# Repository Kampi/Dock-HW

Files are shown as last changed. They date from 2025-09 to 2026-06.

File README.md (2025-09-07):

# ZSWatch-Dock



## 📑 Table of Contents

- [ZSWatch-Dock](#zswatch-dock)
  - [📑 Table of Contents](#-table-of-contents)
  - [📖 About](#-about)
  - [📂 Directory Breakdown](#-directory-breakdown)
  - [Purchasing](#purchasing)
  - [Ressources](#ressources)
  - [👨‍💻 Maintainer](#-maintainer)

## 📖 About

The **ZSWatch-Dock** project provides the hardware design and production files for a docking station tailored to the ZSWatch ecosystem.  
It is built with **KiCad** and integrates a full **CI/CD pipeline** using **KiBot**, ensuring reproducible outputs for documentation, manufacturing, and releases.

Key features:

- 🛠️ Open-source hardware design
- 📦 Automated generation of Gerber, BoM, and documentation via KiBot
- 🔄 Workflow stages (DRAFT → PRELIMINARY → CHECKED → RELEASED) for structured releases
- 📝 Clear documentation and changelog to track progress
- 🌍 Designed with collaboration and transparency in mind

Please check the [wiki](https://github.com/ZSWatch/ZSWatch/wiki) for more information about the project.

## 📂 Directory Breakdown

- **`.github`**: GitHub related files
- **`.gitignore`**: Ignored files list
- **`dock`**: KiCad project for the dock
- **`production`**: Manufacturing outputs (Gerbers, documentation, etc.)
- **`CHANGELOG.md`**: Version history
- **`LICENSE`**: Project license (GPL-3.0)
- **`README.md`**: Project overview

## Purchasing

TBD

## Ressources

- [KiBot Template](https://github.com/nguyen-v/KDT_Hierarchical_KiBot)

## 👨‍💻 Maintainer

- [Daniel Kampert](mailto:danielkameprt@kampis-elektroecke.de)
- [Jakob Krantz](mailto:mail@jakobkrantz.se)

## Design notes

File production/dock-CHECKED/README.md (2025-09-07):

<p align="center" width="100%">
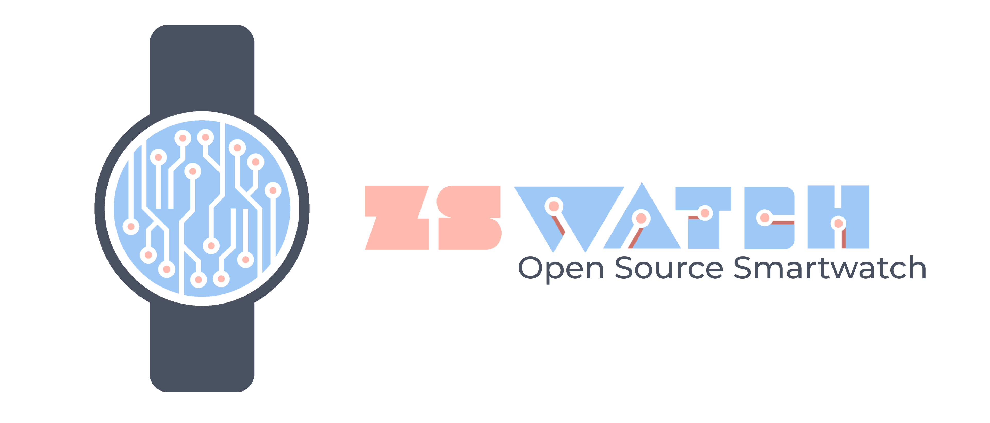
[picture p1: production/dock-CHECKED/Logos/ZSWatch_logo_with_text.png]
  
</p>

<h1 align="center">Dock-HW</h1>

<p align="center" width="100%">
  <a href="https://github.com/ZSWatch/Dock-HW/actions/workflows/dock.yaml">
    
  </a>
</p>

***

<p align="center">
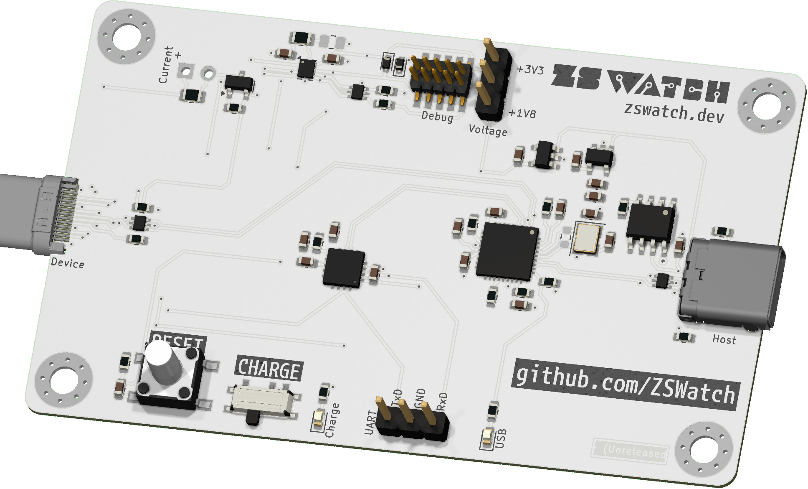
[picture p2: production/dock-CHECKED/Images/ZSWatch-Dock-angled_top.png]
3D Top Angled
  
&nbsp; &nbsp; &nbsp; &nbsp;
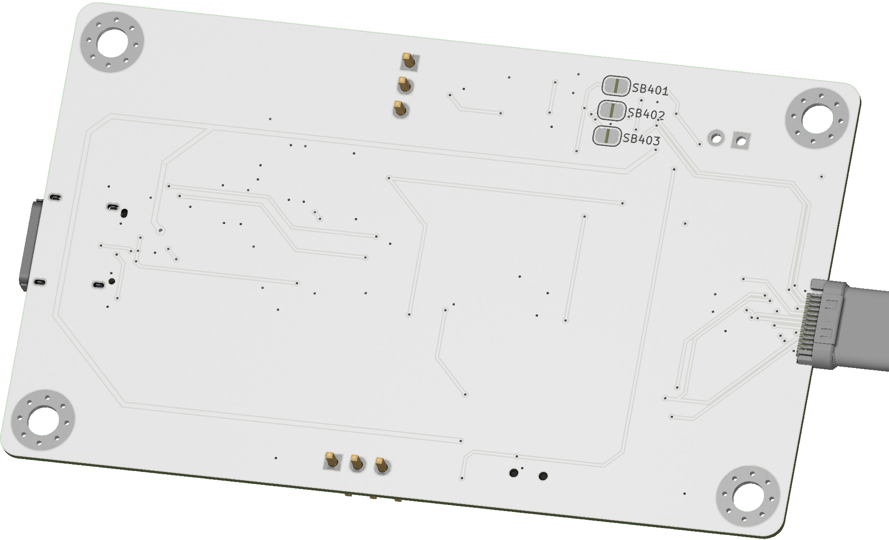
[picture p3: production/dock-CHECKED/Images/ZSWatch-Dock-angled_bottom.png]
3D Bottom Angled
  
</p>

***

## SPECIFICATIONS

| Parameter | Value |
| --- | --- |
| Dimensions | 80.0 × 48.0 mm |

***

## DIRECTORY STRUCTURE

    .
    ├─ Computations       # Misc calculations
    ├─ HTML               # HTML files for generated webpage
    ├─ Images             # Pictures and renders
    │
    ├─ kibot_resources    # External resources for KiBot
    │  ├─ colors          # Color theme for KiCad
    │  ├─ fonts           # Fonts used in the project
    │  ├─ scripts         # External scripts used with KiBot
    │  └─ templates       # Templates for KiBot generated reports
    │
    ├─ kibot_yaml         # KiBot YAML config files
    ├─ KiRI               # KiRI (PCB diff viewer) files
    │
    ├─ lib                # KiCad footprint and symbol libraries
    │  ├─ 3d_models       # Component 3D models
    │  ├─ lib_fp          # Footprint libraries
    │  └─ lib_sym         # Symbol libraries
    │
    ├─ Logos              # Logos
    │
    ├─ Manufacturing      # Assembly and fabrication documents
    │  ├─ Assembly        # Assembly documents (BoM, pos, notes)
    │  │
    │  └─ Fabrication     # Fabrication documents (ZIP, notes)
    │     ├─ Drill Tables # CSV drill tables
    │     └─ Gerbers      # Gerbers
    │
    ├─ Report             # Reports for ERC/DRC
    ├─ Schematic          # PDF of schematic
    ├─ Templates          # Title block templates
    ├─ Testing
    │  └─ Testpoints      # Testpoints tables
    │
    └─ Variants           # Outputs for assembly variants

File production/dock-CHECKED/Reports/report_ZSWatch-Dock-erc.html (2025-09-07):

Logo

| ERC report for ZSWatch-Dock
| Schematic: ZSWatch-Dock Revision: + (Unreleased) Date: 2025-09-07T19:59:50+0000 KiCad Version: 9.0.1 | Errors: 0 Warnings: 18 Total: 18

Sheet / (ZSWatch-Dock.kicad_sch)

Type | Description | Details
lib_symbol_issues | The current configuration does not include the symbol library 'Misc' | @(0.2032 mm, 0.6858 mm): Symbol J401 [Jumper]
footprint_link_issues | The current configuration does not include the footprint library 'Samtec'. | @(0.3048 mm, 0.9271 mm): Symbol X401 [Conn_ARM_JTAG_SWD_10]
footprint_link_issues | The current configuration does not include the footprint library 'Wuerth'. | @(0.3556 mm, 2.3749 mm): Symbol S401 [SW_Push]
lib_symbol_mismatch | Symbol 'FT230XQ' doesn't match copy in library 'Interface_USB' | @(0.889 mm, 2.4384 mm): Symbol IC403 [FT230XQ]
footprint_link_issues | The current configuration does not include the footprint library 'Amphenol'. | @(2.6416 mm, 0.5461 mm): Symbol X404 [USB_C_Receptacle]
lib_symbol_issues | The current configuration does not include the symbol library 'Microchip_Kampi' | @(2.8702 mm, 1.6256 mm): Symbol IC407 [USB2512BT]
lib_symbol_issues | The current configuration does not include the symbol library 'Nexperia' | @(3.683 mm, 0.2921 mm): Symbol Q401 [BSH205G2AR]
unresolved_variable | Unresolved text variable | @(0.8636 mm, 0.3175 mm): Text Box
unresolved_variable | Unresolved text variable | @(0.889 mm, 0.3556 mm): Text Box
unresolved_variable | Unresolved text variable | @(1.524 mm, 0.3175 mm): Text Box
unresolved_variable | Unresolved text variable | @(1.5494 mm, 0.3556 mm): Text Box
unresolved_variable | Unresolved text variable | @(2.1844 mm, 0.3175 mm): Text Box
unresolved_variable | Unresolved text variable | @(2.2098 mm, 0.3556 mm): Text Box

Sheet /Project Architecture/Main/ (Main.kicad_sch)

Type | Description | Details
pin_to_pin | Pins of type Open collector and Tri-state are connected | @(0.4318 mm, 0.8509 mm): Symbol X401 Pin 10 [~{RESET}, Open collector, Line] @(0.9398 mm, 0.8763 mm): Symbol IC405 Pin 9 [B2, Tri-state, Line]
pin_to_pin | Pins of type Bidirectional and Power output are connected | @(2.54 mm, 1.6637 mm): Symbol IC407 Pin 16 [PRTPWR2/BC_EN2, Bidirectional, Line] @(0.2286 mm, 0.4191 mm): Symbol #FLG0403 Pin 1 [Power output, Line]
pin_to_pin | Pins of type Bidirectional and Power output are connected | @(2.54 mm, 1.778 mm): Symbol IC407 Pin 25 [HS_IND/CFG_SEL1, Bidirectional, Line] @(0.2286 mm, 0.4191 mm): Symbol #FLG0403 Pin 1 [Power output, Line]
multiple_net_names | Both +3V3 and VDD are attached to the same items; +3V3 will be used in the netlist | @(0.2032 mm, 2.1209 mm): Symbol #PWR0401 Pin 1 [Power input, Line] @(2.8575 mm, 1.3716 mm): Symbol IC407 Hidden pin 23 [VDD, Power input, Line]
missing_unit | Symbol SW401 has unplaced units [ Unit B ] | @(3.7084 mm, 0.635 mm): Symbol SW401 [SW_DPDT_x2]

Generated by KiBot (https://github.com/INTI-CMNB/KiBot/) v1.8.4

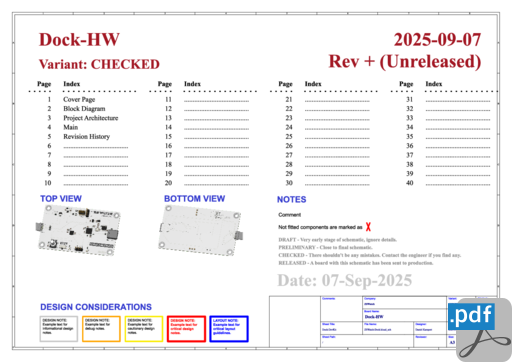
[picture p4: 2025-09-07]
production/dock-CHECKED/HTML/images/cat_pdf_schematic_ZSWatch-Dock-schematic.png

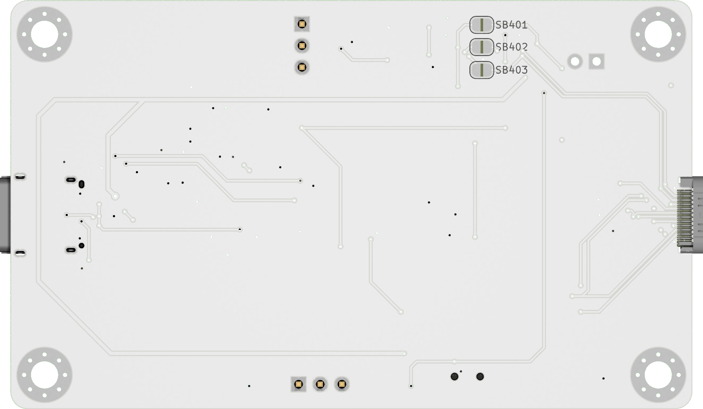
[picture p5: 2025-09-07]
production/dock-CHECKED/Images/ZSWatch-Dock-bottom.png

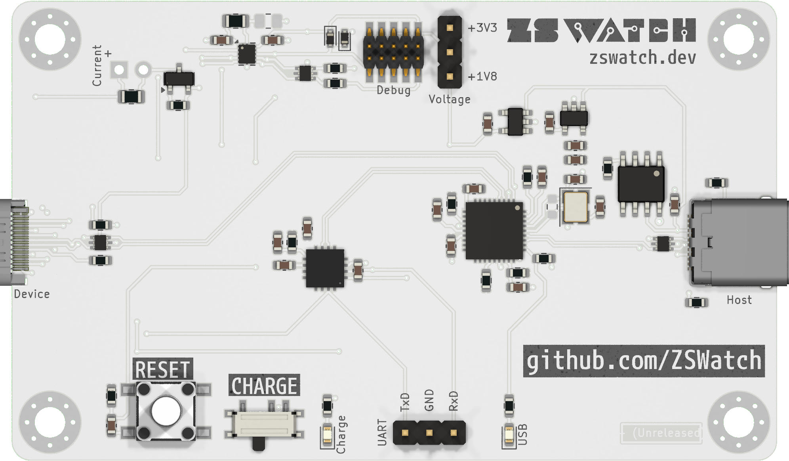
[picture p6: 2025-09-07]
production/dock-CHECKED/Images/ZSWatch-Dock-top.png

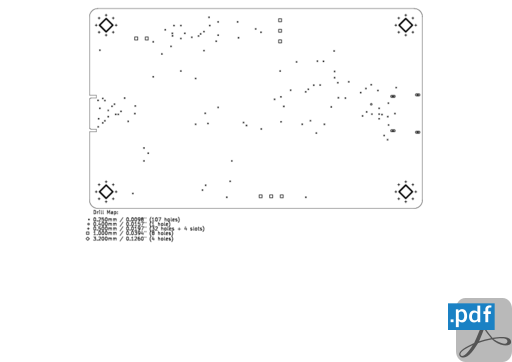
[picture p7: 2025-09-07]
production/dock-CHECKED/HTML/images/cat_pdf_drill_map_ZSWatch-Dock-PTH_drill_map.png

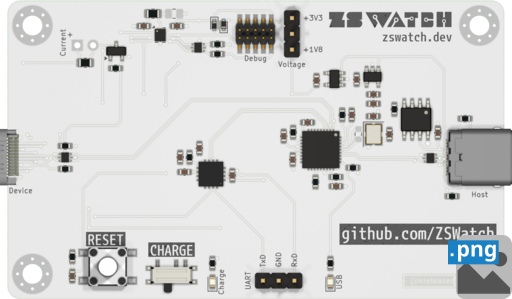
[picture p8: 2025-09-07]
production/dock-CHECKED/HTML/images/cat_png_3d_viewer_top_ZSWatch-Dock-top.png

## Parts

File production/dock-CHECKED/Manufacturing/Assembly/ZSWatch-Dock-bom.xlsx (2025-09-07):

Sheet: BoM
Bill of Materials
Schematic: | ZSWatch-Dock | Component Groups: | 31
Variant: | CHECKED | Component Count: | 61 (58 SMD/ 2 THT)
Revision: |  | Fitted Components: | 61 (58 SMD/ 2 THT)
Date: | 2025-07-13 | Number of PCBs: | 1
KiCad Version: | 9.0.1+1 | Total Components: | 61
Row | Quantity Per PCB | References | Value | Datasheet | Footprint | Description | manf | manf#
1 | 2 | C412 C413 | 18p | https://www.mouser.de/datasheet/2/40/cx5r_KGM-3223198.pdf | C_0603_1608Metric | Unpolarized capacitor, small symbol | KYOCERA AVX | 06031A180KAT2A
2 | 1 | C408 | 470p | https://www.mouser.de/datasheet/2/40/cx5r_KGM-3223198.pdf | C_0603_1608Metric | Unpolarized capacitor, small symbol | KYOCERA AVX | 06031C471K4Z4A
3 | 13 | C401 C403 C404 C405 C406 C407 C409 C414 C415 C416 C417 C418 C419 | 100n | https://www.mouser.de/datasheet/2/447/KEM_C1002_X7R_SMD-3316098.pdf | C_0603_1608Metric | Unpolarized capacitor, small symbol | Kemet | C0603C104M4RAC7411
4 | 1 | C410 | 1u | https://product.tdk.com/system/files/dam/doc/product/capacitor/ceramic/mlcc/catalog/mlcc_commercial_general_en.pdf | C_0603_1608Metric | Unpolarized capacitor, small symbol | TDK | C1608X7R1H105K080AB
5 | 2 | C402 C411 | 2u2 | https://www.mouser.de/datasheet/2/40/cx5r_KGM-3223198.pdf | C_0603_1608Metric | Unpolarized capacitor, small symbol | KYOCERA AVX | 0603YD225KAT4A
6 | 1 | D404 | Charge | https://www.we-online.com/components/products/datasheet/150060GS75020.pdf | LED_0603_1608Metric | Light emitting diode | Wurth Elektronik | 150060YS75020
7 | 2 | D401 D402 | ESD5Zxx | https://www.onsemi.com/pdf/datasheet/esd5z2.5t1-d.pdf | D_SOD-523 | ESD Protection Diode, SOD-523 | onsemi | ESD5Z5.0T5G
8 | 1 | D403 | USB | https://www.mouser.de/datasheet/2/588/LG_L29K_EN-3419084.pdf | LED_0603_1608Metric | Light emitting diode | ams OSRAM | LG L29K-G2J1-24
9 | 1 | IC403 | FT230XQ | https://ftdichip.com/wp-content/uploads/2024/05/DS_FT230X.pdf | QFN-16-1EP_4x4mm_P0.65mm_EP2.1x2.1mm | Full Speed USB to Basic UART, QFN-16 | FTDI | FT230XQ-R
10 | 1 | IC409 | MIC2026-1xM | https://ww1.microchip.com/downloads/aemDocuments/documents/APID/ProductDocuments/DataSheets/MIC2026-MIC2076-Dual-Channel-Power-Distribution-Switch-DS20006443A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 | SOIC-8_3.9x4.9mm_P1.27mm | Dual-channel, high side, power distribution switch, 2.7V-5.5V, Active High Output, SOIC-8 | Microchip Technology | MIC2026-1YM
11 | 1 | IC404 | MIC5219-3.3YM5 | http://ww1.microchip.com/downloads/en/DeviceDoc/MIC5219-500mA-Peak-Output-LDO-Regulator-DS20006021A.pdf | SOT-23-5 | 500mA low dropout linear regulator, fixed 3.3V output, SOT-23-5 | Microchip Technology | MIC5219-3.3YM5-TR
12 | 1 | IC401 | TLV70218_SOT23-5 | http://www.ti.com/lit/ds/symlink/tlv702.pdf | SOT-23-5 | 300mA Low Dropout Voltage Regulator, Fixed Output 1.8V, SOT-23-5 | Texas Instruments | TLV70218DBVRG4
13 | 1 | IC405 | TXB0304RUT | http://www.ti.com/lit/ds/symlink/txb0304.pdf | Texas_R-PUQFN-N12 | 4-Bit Bidirectional Voltage-Level Translator, Auto Direction Sensing, 0.9 - 3.6V APort, 0.9 - 3.6V BPort, Active High Output Enable, Texas_PUQFN-12 | Texas Instruments | TXB0304RUTR
14 | 1 | IC407 | USB2512BT | https://ww1.microchip.com/downloads/aemDocuments/documents/UNG/ProductDocuments/DataSheets/USB251xB-xBi-Data-Sheet-DS00001692.pdf | QFN-36-1EP_6x6mm_P0.5mm_EP3.7x3.7mm |  | Microchip Technology | USB2512BT/M2
15 | 3 | IC402 IC406 IC408 | USBLC6-2P6 | https://www.st.com/resource/en/datasheet/usblc6-2.pdf | SOT-666 | Very low capacitance ESD protection diode, 2 data-line, SOT-666 | STMicroelectronics | USBLC6-2P6
16 | 1 | J401 | Jumper | https://www.we-online.com/katalog/datasheet/60900213421.pdf |  | Generic jumper cap | Würth Elektronik | 60900213421
17 | 2 | J402 X402 | Voltage | https://cdn.amphenol-cs.com/media/wysiwyg/files/documentation/datasheet/boardwiretoboard/bwb_econostik_254headers.pdf | PinHeader_1x03_P2.54mm_Vertical | Generic connector, single row, 01x03, script generated (kicad-library-utils/schlib/autogen/connector/) | Amphenol FCI | 10129378-936001BLF
18 | 1 | Q401 | BSH205G2AR | https://assets.nexperia.com/documents/data-sheet/BSH205G2A.pdf | SOT-23 | -2A Id, -20V Vds, P-Channel MOSFET, SOT-23 | Nexperia | BSH205G2AR
19 | 2 | R405 R418 | 0R | https://www.mouser.de/datasheet/2/54/cr-1858361.pdf | R_0805_2012Metric | Resistor, small symbol | Bourns | CR0805-J/-000ELF
20 | 2 | R402 R403 | 22R | https://www.mouser.de/datasheet/2/54/cr-1858361.pdf | R_0603_1608Metric | Resistor, small symbol | Bourns | CR0603-JW-220ELF
21 | 1 | R421 | 620R | https://www.mouser.de/datasheet/2/54/cr-1858361.pdf | R_0603_1608Metric | Resistor, small symbol | Bourns | CR0603-JW-621ELF
22 | 1 | R407 | 3k3 | https://www.vishay.com/doc?20035 | R_0603_1608Metric | Resistor, small symbol | Vishay | CRCW06033K300FKEA
23 | 4 | R409 R410 R415 R416 | 5k1 | https://www.vishay.com/doc?20035 | R_0603_1608Metric | Resistor, small symbol | Vishay | CRCW06035K10FKEA
24 | 8 | R401 R404 R408 R412 R413 R414 R419 R420 | 100k | https://www.mouser.de/datasheet/2/447/YAGEO_PYu_RC_Group_51_RoHS_L_12-3313492.pdf | R_0603_1608Metric | Resistor, small symbol | YAGEO | RC0603FR-07100KL
25 | 1 | R417 | 12k / 1% | https://www.mouser.de/datasheet/2/54/cr-1858361.pdf | R_0603_1608Metric | Resistor, small symbol | Bourns | CR0603-FX-1202ELF
26 | 1 | S401 | Reset | https://www.we-online.com/components/products/datasheet/430182050816.pdf | WS-TASV-6x6 |  | Wurth Elektronik | 430182050816
27 | 1 | SW401 | Charge | https://ckswitches.com/media/1424/pcm.pdf | SW_SPDT_PCM12 | Switch, dual pole double throw, separate symbols | C&K | PCM12SMTR
28 | 1 | X401 | Debug | https://www.we-online.com/components/products/datasheet/62101021021.pdf | SHF-105-01-L-D-SM-TR | Cortex Debug Connector, standard ARM Cortex-M SWD and JTAG interface | Wurth Elektronik | 62101021021
29 | 1 | X404 | Device | https://cdn.amphenol-cs.com/media/wysiwyg/files/drawing/10133475.pdf | 10133475-10001LF | USB Full-Featured Type-C edge connector | Amphenol Commercial Products | 10133475-10001LF
30 | 1 | X403 | Host | https://www.usb.org/sites/default/files/documents/usb_type-c.zip | USB_C_Receptacle_Amphenol_12401610E4-2A | USB Full-Featured Type-C Receptacle connector | Amphenol Commercial Products | 12401610E4-2A
31 | 1 | Y401 | 24 MHz | https://www.mouser.de/datasheet/2/3/ABM8G-3318032.pdf | Crystal_SMD_Abracon_ABM8G-4Pin_3.2x2.5mm | Four pin crystal, GND on pins 2 and 4 | ABRACON | ABM8G-24.000MHZ-B4Y-T

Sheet: Costs
Bill of Materials
Schematic: | ZSWatch-Dock |  |  |  |  | Board Qty: | 1
Variant: | CHECKED |  |  |  |  | Unit Cost: | $0.00
Revision: |  |  |  |  |  | Total Cost: | $0.00 |  |  |  |  | $0.00 | 0 of 31 parts found
Date: | 2025-07-13
KiCad Version: | 9.0.1+1
Global Part Info |  |  |  |  |  |  |  | Mouser
References | Value | Footprint | Manf | Manf# | Build Quantity | Unit$ | Ext$ | Avail | Purch | Unit$ | MOQ | Ext$ | Cat#
C412 C413 | 18p | C_0603_1608Metric | KYOCERA AVX | 06031A180KAT2A (https://www.mouser.de/datasheet/2/40/cx5r_KGM-3223198.pdf) | 2
C408 | 470p | C_0603_1608Metric | KYOCERA AVX | 06031C471K4Z4A (https://www.mouser.de/datasheet/2/40/cx5r_KGM-3223198.pdf) | 1
C401 C403 C404 C405 C406 C407 C409 C414 C415 C416 C417 C418 C419 | 100n | C_0603_1608Metric | Kemet | C0603C104M4RAC7411 (https://www.mouser.de/datasheet/2/447/KEM_C1002_X7R_SMD-3316098.pdf) | 13
C410 | 1u | C_0603_1608Metric | TDK | C1608X7R1H105K080AB (https://product.tdk.com/system/files/dam/doc/product/capacitor/ceramic/mlcc/catalog/mlcc_commercial_general_en.pdf) | 1
C402 C411 | 2u2 | C_0603_1608Metric | KYOCERA AVX | 0603YD225KAT4A (https://www.mouser.de/datasheet/2/40/cx5r_KGM-3223198.pdf) | 2
D404 | Charge | LED_0603_1608Metric | Wurth Elektronik | 150060YS75020 (https://www.we-online.com/components/products/datasheet/150060GS75020.pdf) | 1
D401 D402 | ESD5Zxx | D_SOD-523 | onsemi | ESD5Z5.0T5G (https://www.onsemi.com/pdf/datasheet/esd5z2.5t1-d.pdf) | 2
D403 | USB | LED_0603_1608Metric | ams OSRAM | LG L29K-G2J1-24 (https://www.mouser.de/datasheet/2/588/LG_L29K_EN-3419084.pdf) | 1
IC403 | FT230XQ | QFN-16-1EP_4x4mm_P0.65mm_EP2.1x2.1mm | FTDI | FT230XQ-R (https://ftdichip.com/wp-content/uploads/2024/05/DS_FT230X.pdf) | 1
IC409 | MIC2026-1xM | SOIC-8_3.9x4.9mm_P1.27mm | Microchip Technology | MIC2026-1YM (https://ww1.microchip.com/downloads/aemDocuments/documents/APID/ProductDocuments/DataSheets/MIC2026-MIC2076-Dual-Channel-Power-Distribution-Switch-DS20006443A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) | 1
IC404 | MIC5219-3.3YM5 | SOT-23-5 | Microchip Technology | MIC5219-3.3YM5-TR (http://ww1.microchip.com/downloads/en/DeviceDoc/MIC5219-500mA-Peak-Output-LDO-Regulator-DS20006021A.pdf) | 1
IC401 | TLV70218_SOT23-5 | SOT-23-5 | Texas Instruments | TLV70218DBVRG4 (http://www.ti.com/lit/ds/symlink/tlv702.pdf) | 1
IC405 | TXB0304RUT | Texas_R-PUQFN-N12 | Texas Instruments | TXB0304RUTR (http://www.ti.com/lit/ds/symlink/txb0304.pdf) | 1
IC407 | USB2512BT | QFN-36-1EP_6x6mm_P0.5mm_EP3.7x3.7mm | Microchip Technology | USB2512BT/M2 (https://ww1.microchip.com/downloads/aemDocuments/documents/UNG/ProductDocuments/DataSheets/USB251xB-xBi-Data-Sheet-DS00001692.pdf) | 1
IC402 IC406 IC408 | USBLC6-2P6 | SOT-666 | STMicroelectronics | USBLC6-2P6 (https://www.st.com/resource/en/datasheet/usblc6-2.pdf) | 3
J401 | Jumper |  | Würth Elektronik | 60900213421 (https://www.we-online.com/katalog/datasheet/60900213421.pdf) | 1
J402 X402 | Voltage | PinHeader_1x03_P2.54mm_Vertical | Amphenol FCI | 10129378-936001BLF (https://cdn.amphenol-cs.com/media/wysiwyg/files/documentation/datasheet/boardwiretoboard/bwb_econostik_254headers.pdf) | 2
Q401 | BSH205G2AR | SOT-23 | Nexperia | BSH205G2AR (https://assets.nexperia.com/documents/data-sheet/BSH205G2A.pdf) | 1
R405 R418 | 0R | R_0805_2012Metric | Bourns | CR0805-J/-000ELF (https://www.mouser.de/datasheet/2/54/cr-1858361.pdf) | 2
R402 R403 | 22R | R_0603_1608Metric | Bourns | CR0603-JW-220ELF (https://www.mouser.de/datasheet/2/54/cr-1858361.pdf) | 2
R421 | 620R | R_0603_1608Metric | Bourns | CR0603-JW-621ELF (https://www.mouser.de/datasheet/2/54/cr-1858361.pdf) | 1
R407 | 3k3 | R_0603_1608Metric | Vishay | CRCW06033K300FKEA (https://www.vishay.com/doc?20035) | 1
R409 R410 R415 R416 | 5k1 | R_0603_1608Metric | Vishay | CRCW06035K10FKEA (https://www.vishay.com/doc?20035) | 4
R401 R404 R408 R412 R413 R414 R419 R420 | 100k | R_0603_1608Metric | YAGEO | RC0603FR-07100KL (https://www.mouser.de/datasheet/2/447/YAGEO_PYu_RC_Group_51_RoHS_L_12-3313492.pdf) | 8
R417 | 12k / 1% | R_0603_1608Metric | Bourns | CR0603-FX-1202ELF (https://www.mouser.de/datasheet/2/54/cr-1858361.pdf) | 1
S401 | Reset | WS-TASV-6x6 | Wurth Elektronik | 430182050816 (https://www.we-online.com/components/products/datasheet/430182050816.pdf) | 1
SW401 | Charge | SW_SPDT_PCM12 | C&K | PCM12SMTR (https://ckswitches.com/media/1424/pcm.pdf) | 1
X401 | Debug | SHF-105-01-L-D-SM-TR | Wurth Elektronik | 62101021021 (https://www.we-online.com/components/products/datasheet/62101021021.pdf) | 1
X404 | Device | 10133475-10001LF | Amphenol Commercial Products | 10133475-10001LF (https://cdn.amphenol-cs.com/media/wysiwyg/files/drawing/10133475.pdf) | 1
X403 | Host | USB_C_Receptacle_Amphenol_12401610E4-2A | Amphenol Commercial Products | 12401610E4-2A (https://www.usb.org/sites/default/files/documents/usb_type-c.zip) | 1
Y401 | 24 MHz | Crystal_SMD_Abracon_ABM8G-4Pin_3.2x2.5mm | ABRACON | ABM8G-24.000MHZ-B4Y-T (https://www.mouser.de/datasheet/2/3/ABM8G-3318032.pdf) | 1
 |  |  |  |  |  | Total Purchase: | $0.00 | Buy here (https://mouser.com/bom/) |  |  |  | $0.00
Created: | 2025-09-07 20:03:14 |  |  |  |  | Purchase description:
KiCost® v1.1.20 + KiBot v1.8.4

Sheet: Colors
Columns colors
KiCad Fields (default)
Generated Fields
User Fields
Empty Fields
Costs sheet colors
Best price
No manufacturer or distributor code
Not available
Purchase quantity is more than what is available
Minimum order quantity not respected
Total available part quantity is less than needed
Total purchased part quantity is less than needed
This part is obsolete
This part is listed but is not normally stocked

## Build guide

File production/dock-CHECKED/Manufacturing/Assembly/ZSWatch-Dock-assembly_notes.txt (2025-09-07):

ASSEMBLY NOTES (UNLESS OTHERWISE SPECIFIED)

1)	DO NOT POPULATE PARTS ARE MARKED WITH A RED CROSS.

2)	DO NOT POPULATE PARTS ARE NOT PRESENT IN THE BOM.

3)	IF CONFLICTING INFORMATION IS FOUND BETWEEN THE ASSEMBLY
	FILE AND BOM, BOM SHOULD BE USED AS THE MAIN SOURCE.

4)	CONFORMAL COATING IS NOT REQUIRED.

5)	DOT IDENTIFIES PIN #1 LOCATION AND DEVICE ORIENTATION
	WHEN VIEWED FROM THE TOP.

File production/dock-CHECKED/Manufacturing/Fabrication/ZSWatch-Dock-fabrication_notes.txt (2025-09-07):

FABRICATION NOTES (UNLESS OTHERWISE SPECIFIED)

1)	FABRICATE PER IPC-6012A CLASS 2.

2)	OUTLINE DEFINED IN SEPARATE GERBER FILE WITH
	"Edge_Cuts.GBR" SUFFIX.

	DIMENSIONS OF CIRCUMSIZED RECTANGLE SHOWN ON THIS
	DRAWING FOR REFERENCE ONLY.

3)	SEE SEPARATE DRILL FILES WITH ".DRL" SUFFIX 
	FOR HOLE LOCATIONS.

	SELECTED HOLE LOCATIONS SHOWN ON THIS DRAWING 
	FOR REFERENCE ONLY.

4)	SURFACE FINISH: HAL SNPB

5)	SOLDERMASK ON BOTH SIDES OF THE BOARD SHALL 
	BE LPI, COLOR WHITE.

6)	SILK SCREEN LEGEND TO BE APPLIED PER LAYER 
	STACKUP USING BLACK NON-CONDUCTIVE EPOXY INK.

7)	ALL VIAS ARE TENTED ON BOTH SIDES UNLESS 
	SOLDERMASK OPENED IN GERBER.

8)	VENDOR SHOULD FOLLOW ROHS COMPLIANT PROCESS 
	AND Pb FREE FOR MANUFACTURING

9)	PCB MATERIAL REQUIREMENTS:

	A.	FLAMMABILITY RATING MUST MEET OR EXCEED 
		UL94V-0 REQUIREMENTS.
	B.	Tg 150 C OR EQUIVALENT.
	C.	EQUIVALENT MATERIAL SHALL BE RoHS COMPLIANT, 
		HALOGEN FREE AND APPROVED BY ZSWATCH.

10)	DESIGN GEOMETRY MINIMUM FEATURE SIZES:

	BOARD SIZE				80.000 × 48.000 mm
	BOARD THICKNESS		0.761 mm
	TRACE WIDTH			0.170 mm
	TRACE TO TRACE		0.125 mm
	MIN. HOLE (PTH)			0.250 mm
	MIN. HOLE (NPTH)		0.650 mm
	ANNULAR RING			0.100 mm
	COPPER TO HOLE		0.100 mm
	COPPER TO EDGE		0.100 mm
	HOLE TO HOLE			0.250 mm

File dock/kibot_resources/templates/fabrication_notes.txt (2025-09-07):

FABRICATION NOTES (UNLESS OTHERWISE SPECIFIED)

1)	FABRICATE PER IPC-6012A CLASS 2.

2)	OUTLINE DEFINED IN SEPARATE GERBER FILE WITH
	"Edge_Cuts.GBR" SUFFIX.

	DIMENSIONS OF CIRCUMSIZED RECTANGLE SHOWN ON THIS
	DRAWING FOR REFERENCE ONLY.

3)	SEE SEPARATE DRILL FILES WITH ".DRL" SUFFIX 
	FOR HOLE LOCATIONS.

	SELECTED HOLE LOCATIONS SHOWN ON THIS DRAWING 
	FOR REFERENCE ONLY.

4)	SURFACE FINISH: ${pcb_finish_cap}

5)	SOLDERMASK ON BOTH SIDES OF THE BOARD SHALL 
	BE LPI, COLOR ${solder_mask_color_text_cap}.

6)	SILK SCREEN LEGEND TO BE APPLIED PER LAYER 
	STACKUP USING ${silk_screen_color_text_cap} NON-CONDUCTIVE EPOXY INK.

7)	ALL VIAS ARE TENTED ON BOTH SIDES UNLESS 
	SOLDERMASK OPENED IN GERBER.

8)	VENDOR SHOULD FOLLOW ROHS COMPLIANT PROCESS 
	AND Pb FREE FOR MANUFACTURING

9)	PCB MATERIAL REQUIREMENTS:

	A.	FLAMMABILITY RATING MUST MEET OR EXCEED 
		UL94V-0 REQUIREMENTS.
	B.	Tg 150 C OR EQUIVALENT.
	C.	EQUIVALENT MATERIAL SHALL BE RoHS COMPLIANT, 
		HALOGEN FREE AND APPROVED BY ${COMPANY_cap}.

10)	DESIGN GEOMETRY MINIMUM FEATURE SIZES:

	BOARD SIZE				${bb_w_mm} × ${bb_h_mm} mm
	BOARD THICKNESS		${thickness_mm} mm
	TRACE WIDTH			${track_mm} mm
	TRACE TO TRACE		${clearance_mm} mm
	MIN. HOLE (PTH)			${drill_pth_real_mm} mm
	MIN. HOLE (NPTH)		${drill_npth_real_mm} mm
	ANNULAR RING			${oar_mm} mm
	COPPER TO HOLE		${c2h_mm} mm
	COPPER TO EDGE		${c2e_mm} mm
	HOLE TO HOLE			${h2h_mm} mm
#?stackup and impedance_controlled

#?stackup and impedance_controlled
11)	REFER TO IMPEDANCE TABLE FOR IMPEDANCE CONTROL REQUIREMENTS.
#?stackup and impedance_controlled

#?stackup and impedance_controlled
12)	CONFIRM SPACE WIDTHS AND SPACINGS.

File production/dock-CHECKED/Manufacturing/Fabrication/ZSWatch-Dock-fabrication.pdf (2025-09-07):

# Top Fabrication (Scale 1:1)

# Dock-HW Fabrication Document

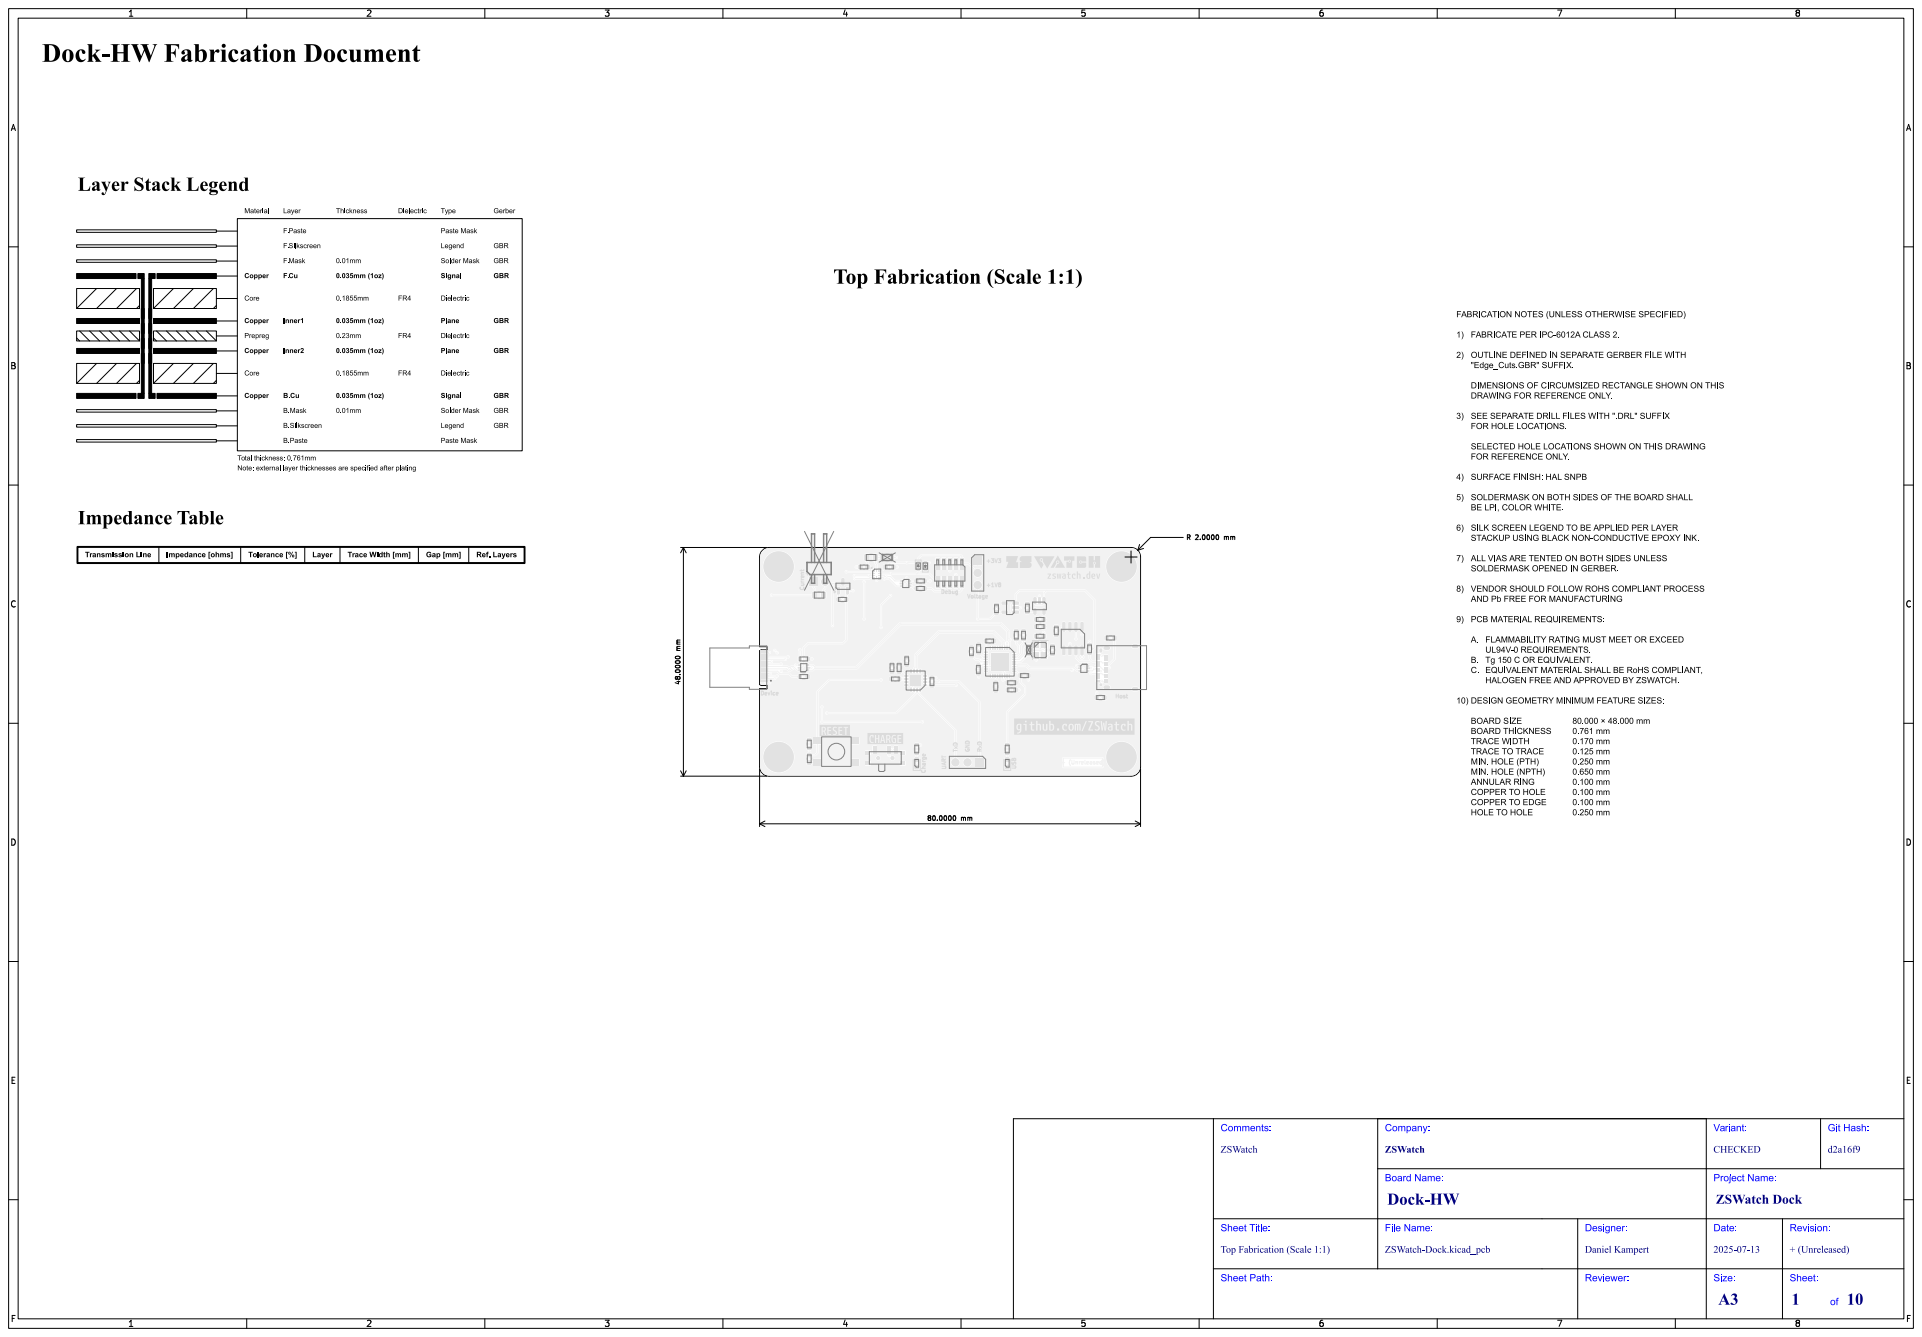
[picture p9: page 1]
Git Hash:; ZSWatch; Comments:; Sheet Path:; Sheet Title:; File Name:; Dock-HW; ZSWatch Dock; Company:; CHECKED; Variant:; Board Name:; ZSWatch-Dock.kicad_pcb; Daniel Kampert; Designer:; Reviewer:; Project Name:; Date:; + (Unreleased); Revision:; Size:; Sheet:; USB; Voltage Debug; Device; Charge; UART; Current; Host; TxD; GND; RxD

Top Fabrication (Scale 1:1)

# Bottom Fabrication (Scale 1:1)

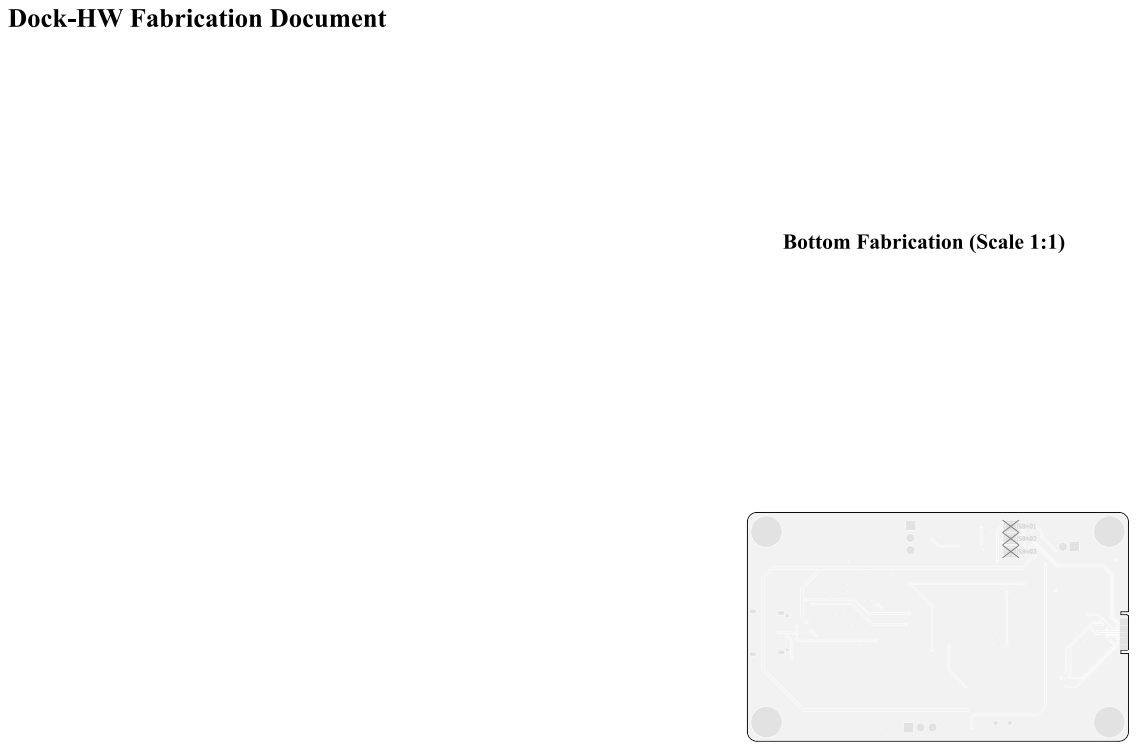
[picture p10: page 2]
Git; Hash:; ZSWatch; Comments:; Sheet Title:; File Name:; Dock-HW; ZSWatch Dock; Company:; CHECKED; Variant:; Board Name:; ZSWatch-Dock.kicad_pcb; Daniel Kampert; Designer:; Project Name:; Date:; + (Unreleased); Revision:

Bottom Fabrication (Scale 1:1)

# Drill Drawing L1 - L4 (Scale 1:1)

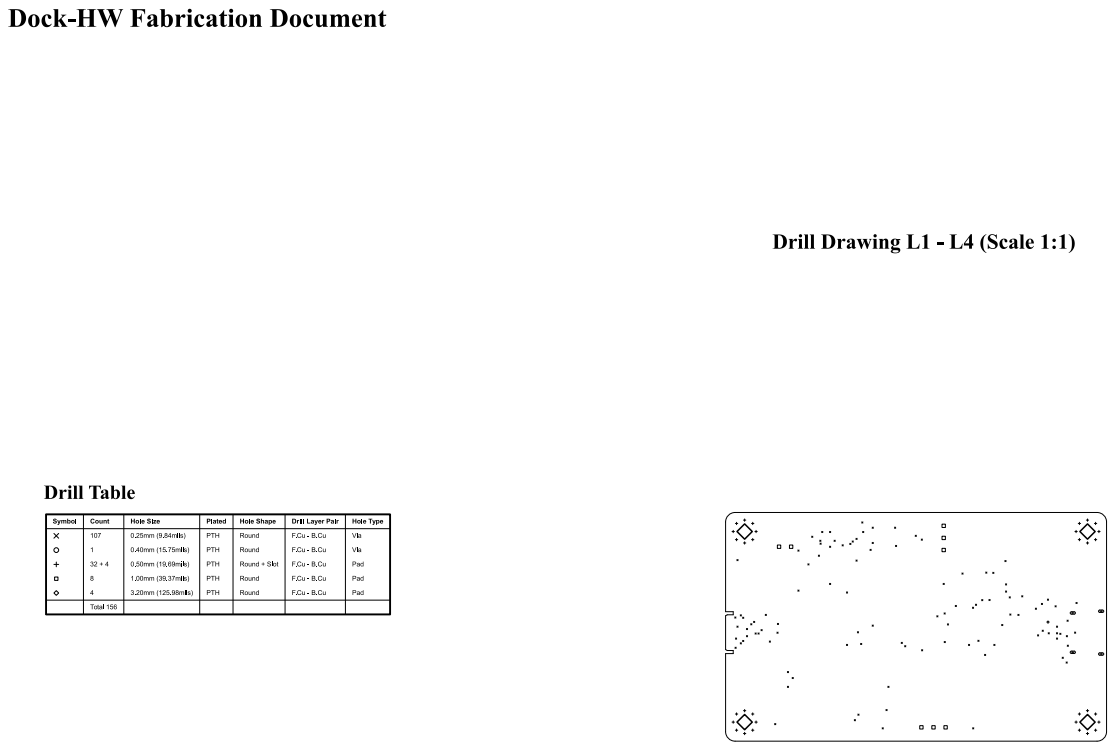
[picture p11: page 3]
Git; Hash:; ZSWatch; Comments:; Drill Drawing (L1 - L4); Sheet Title:; File Name:; Dock-HW; ZSWatch Dock; Company:; CHECKED; Variant:; Board Name:; ZSWatch-Dock.kicad_pcb; Daniel Kampert; Designer:; Project Name:; Date:; + (Unreleased); Revision:

# Drill Drawing L1 - L4 (Scale 1:1)

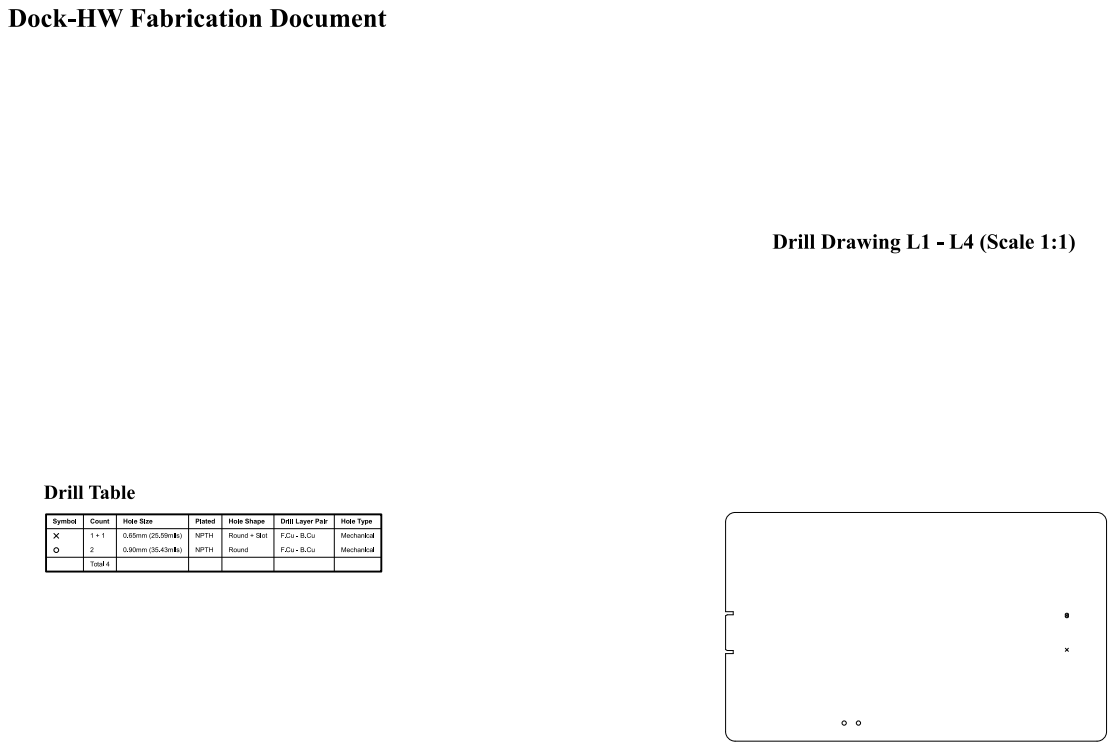
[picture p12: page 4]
Git; Hash:; ZSWatch; Comments:; Drill Drawing (L1 - L4); Sheet Title:; File Name:; Dock-HW; ZSWatch Dock; Company:; CHECKED; Variant:; Board Name:; ZSWatch-Dock.kicad_pcb; Daniel Kampert; Designer:; Project Name:; Date:; + (Unreleased); Revision:

# Top Test Points (Scale 1:1)

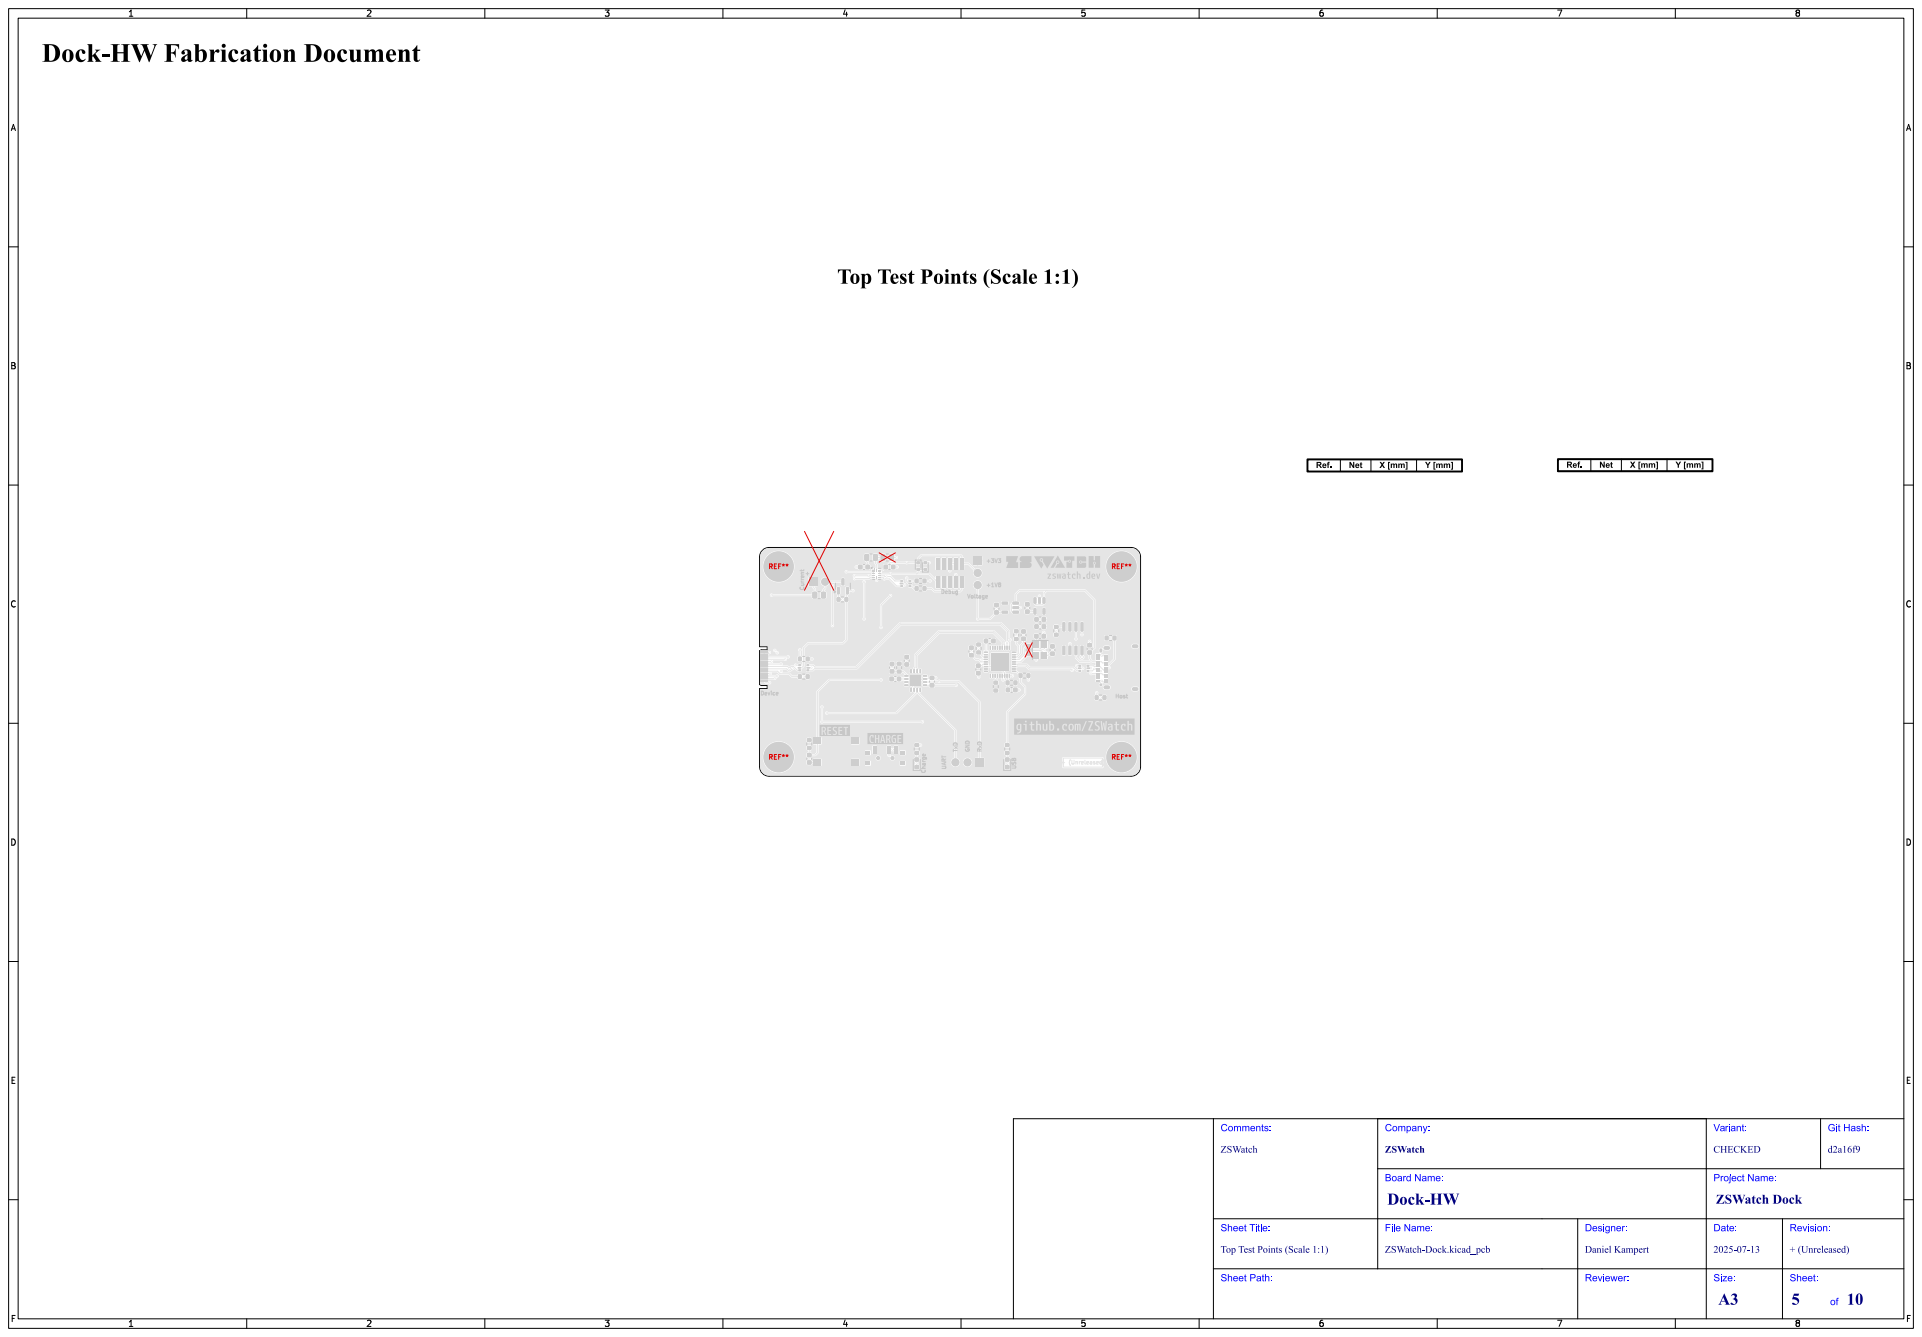
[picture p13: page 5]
Git; Hash:; ZSWatch; Comments:; Sheet Title:; File Name:; Dock-HW; ZSWatch Dock; Company:; CHECKED; Variant:; Board Name:; ZSWatch-Dock.kicad_pcb; Daniel Kampert; Designer:; Project Name:; Date:; + (Unreleased); Revision:; REF**; USB; Voltage Debug; Device; Charge; UART; Current; Host; TxD; GND; RxD

Top Test Points (Scale 1:1)

# Bottom Test Points (Scale 1:1)

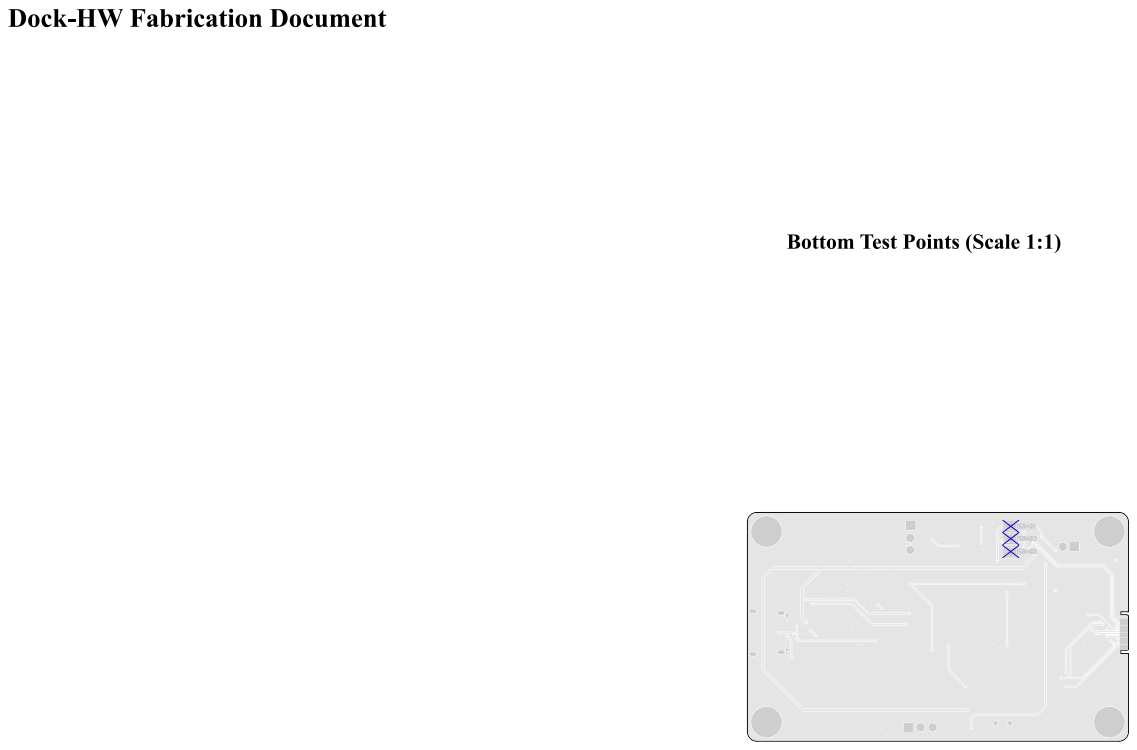
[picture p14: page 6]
Git; Hash:; ZSWatch; Comments:; Sheet Title:; File Name:; Dock-HW; ZSWatch Dock; Company:; CHECKED; Variant:; Board Name:; ZSWatch-Dock.kicad_pcb; Daniel Kampert; Designer:; Project Name:; Date:; + (Unreleased); Revision:

Bottom Test Points (Scale 1:1)

# F.Cu (Scale 1:1)

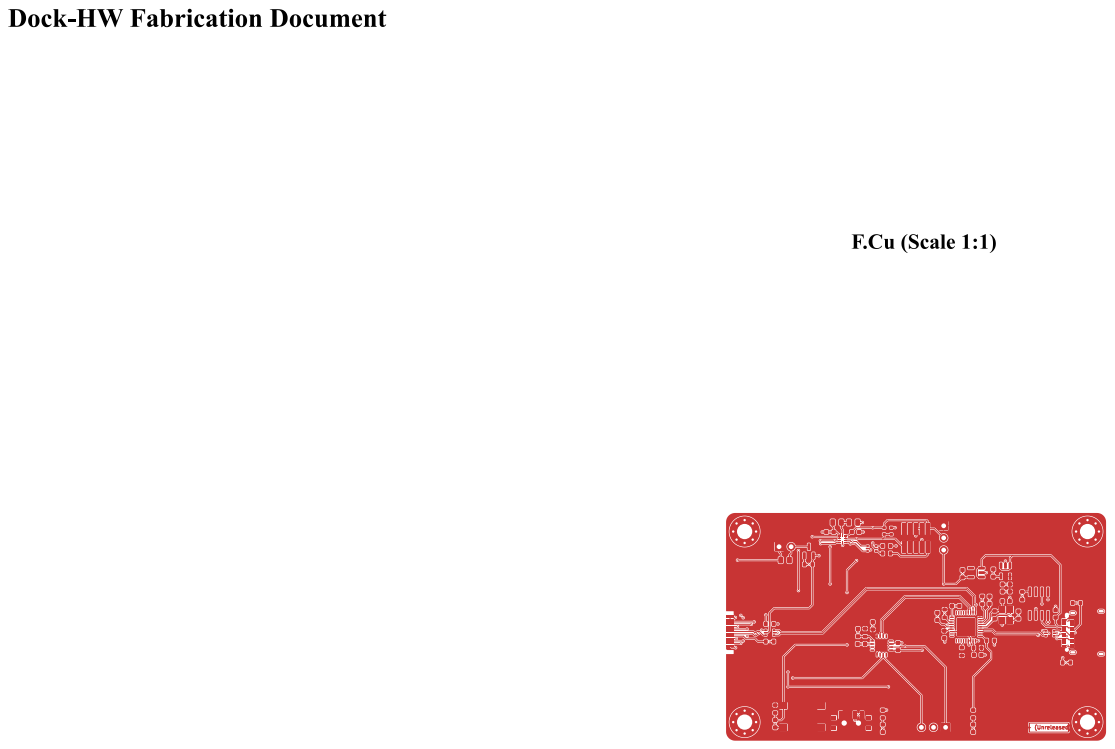
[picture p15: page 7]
Git; Hash:; ZSWatch; Comments:; F.Cu (Scale 1:1); Sheet Title:; File Name:; Dock-HW; ZSWatch Dock; Company:; CHECKED; Variant:; Board Name:; ZSWatch-Dock.kicad_pcb; Daniel Kampert; Designer:; Project Name:; Date:; + (Unreleased); Revision:

# Inner1 (Scale 1:1)

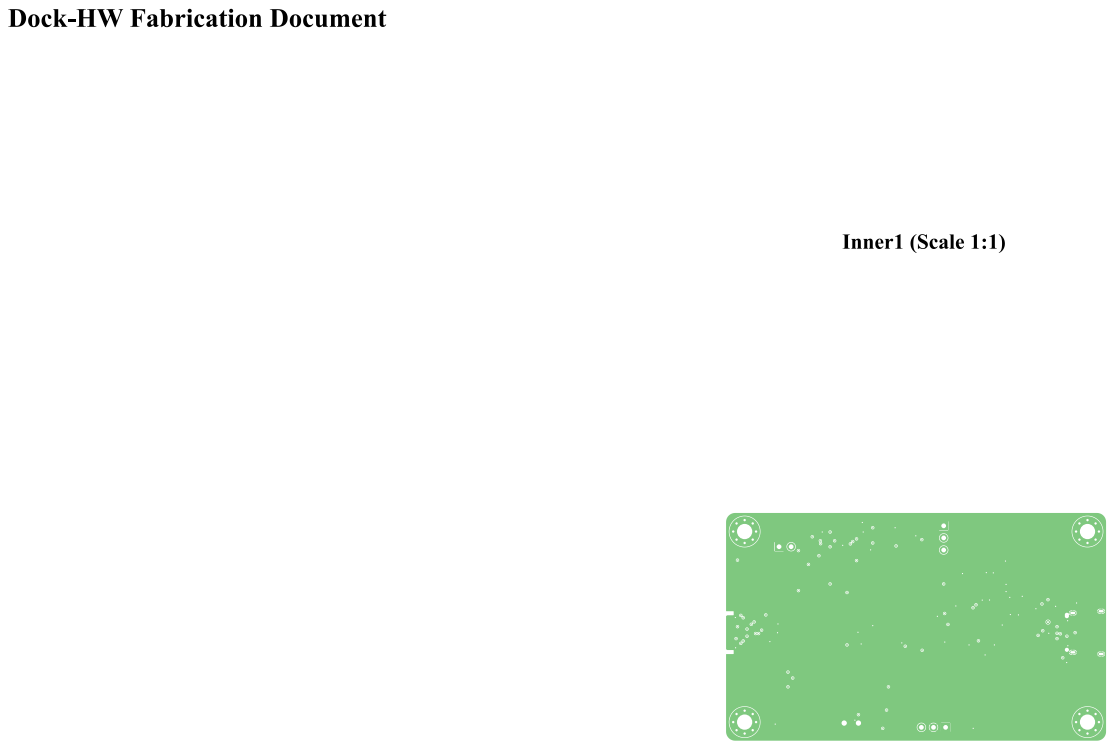
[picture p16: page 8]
Git; Hash:; ZSWatch; Comments:; Inner1 (Scale 1:1); Sheet Title:; File Name:; Dock-HW; ZSWatch Dock; Company:; CHECKED; Variant:; Board Name:; ZSWatch-Dock.kicad_pcb; Daniel Kampert; Designer:; Project Name:; Date:; + (Unreleased); Revision:

# Inner2 (Scale 1:1)

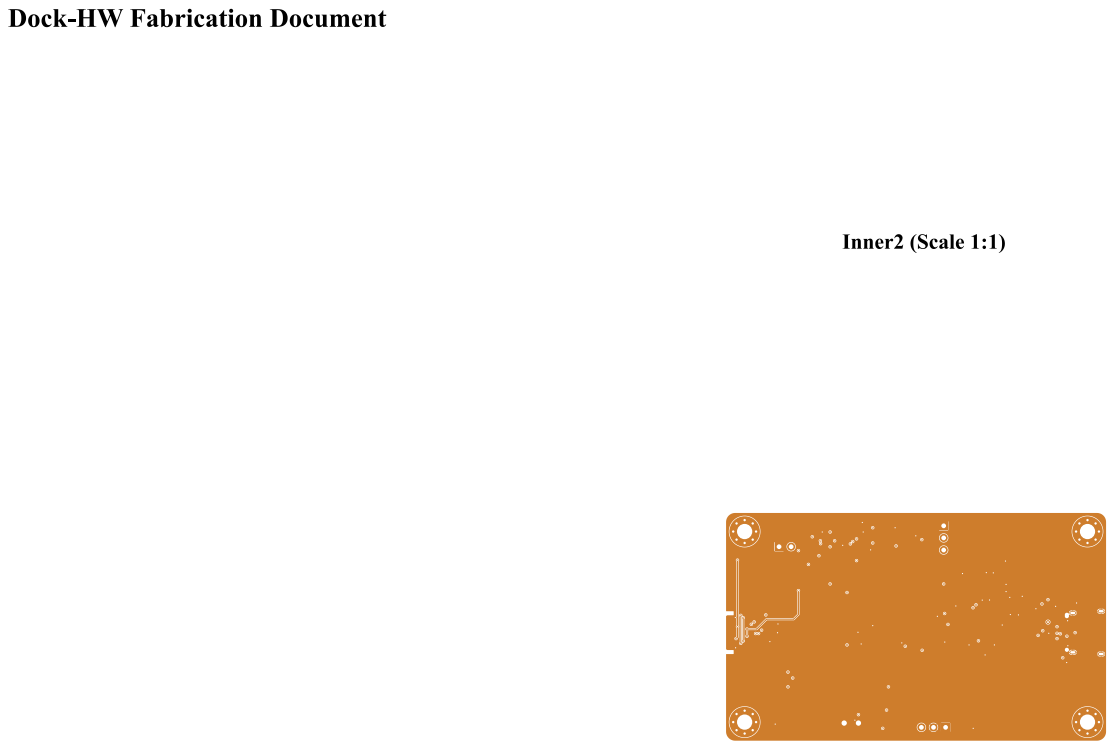
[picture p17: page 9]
Git; Hash:; ZSWatch; Comments:; Inner2 (Scale 1:1); Sheet Title:; File Name:; Dock-HW; ZSWatch Dock; Company:; CHECKED; Variant:; Board Name:; ZSWatch-Dock.kicad_pcb; Daniel Kampert; Designer:; Project Name:; Date:; + (Unreleased); Revision:

# B.Cu (Scale 1:1)

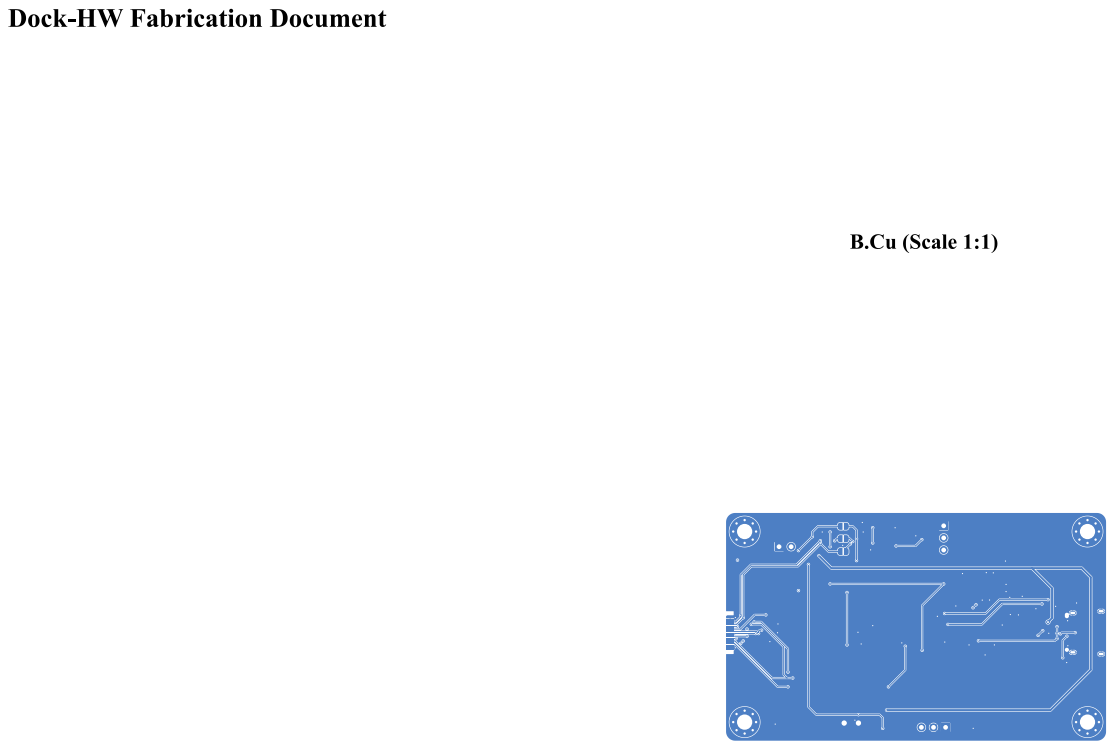
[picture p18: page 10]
Git; Hash:; ZSWatch; Comments:; B.Cu (Scale 1:1); Sheet Title:; File Name:; Dock-HW; ZSWatch Dock; Company:; CHECKED; Variant:; Board Name:; ZSWatch-Dock.kicad_pcb; Daniel Kampert; Designer:; Project Name:; Date:; + (Unreleased); Revision:

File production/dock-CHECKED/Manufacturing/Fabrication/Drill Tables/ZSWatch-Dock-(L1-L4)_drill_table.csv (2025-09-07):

Count | Hole Size | Plated | Hole Shape | Drill Layer Pair | Hole Type
107 | 0.25mm (9.84mils) | PTH | Round | F.Cu - B.Cu | Via
1 | 0.40mm (15.75mils) | PTH | Round | F.Cu - B.Cu | Via
32 + 4 | 0.50mm (19.69mils) | PTH | Round + Slot | F.Cu - B.Cu | Pad
8 | 1.00mm (39.37mils) | PTH | Round | F.Cu - B.Cu | Pad
4 | 3.20mm (125.98mils) | PTH | Round | F.Cu - B.Cu | Pad
Total 156

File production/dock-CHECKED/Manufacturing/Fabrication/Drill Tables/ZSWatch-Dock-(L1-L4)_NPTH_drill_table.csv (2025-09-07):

Count | Hole Size | Plated | Hole Shape | Drill Layer Pair | Hole Type
1 + 1 | 0.65mm (25.59mils) | NPTH | Round + Slot | F.Cu - B.Cu | Mechanical
2 | 0.90mm (35.43mils) | NPTH | Round | F.Cu - B.Cu | Mechanical
Total 4

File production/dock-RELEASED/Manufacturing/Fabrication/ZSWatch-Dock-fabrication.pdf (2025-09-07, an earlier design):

# Top Fabrication (Scale 1:1)

# Dock-HW Fabrication Document

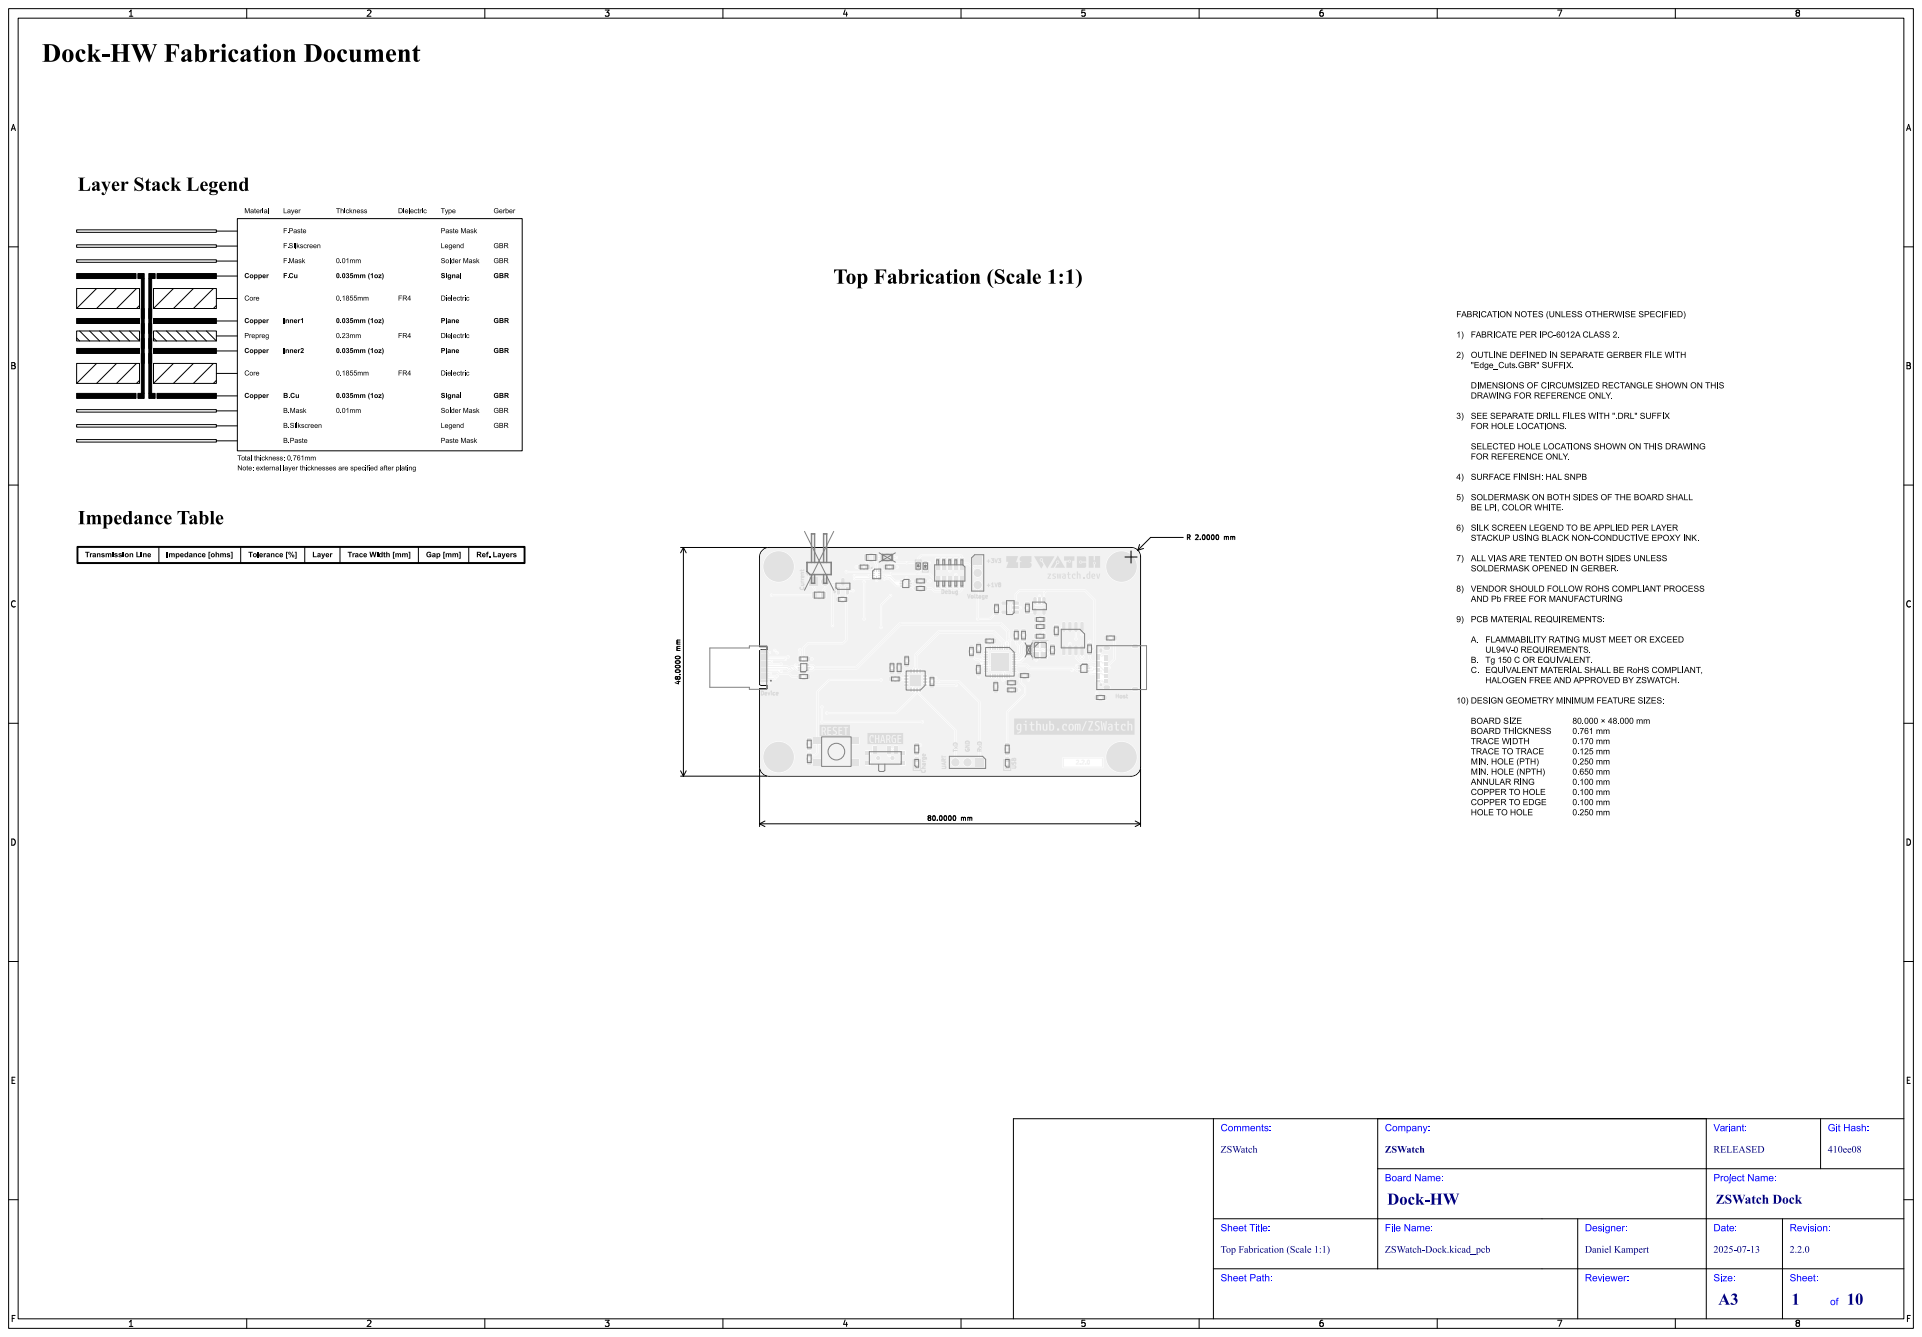
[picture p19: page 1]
Git Hash:; ZSWatch; Comments:; Sheet Path:; Sheet Title:; File Name:; Dock-HW; ZSWatch Dock; Company:; RELEASED; Variant:; Board Name:; ZSWatch-Dock.kicad_pcb; Daniel Kampert; Designer:; Reviewer:; Project Name:; Date:; Revision:; Size:; Sheet:; USB; Voltage Debug; Device; Charge; UART; Current; Host; TxD; GND; RxD

Top Fabrication (Scale 1:1)

# Bottom Fabrication (Scale 1:1)

Git; Hash:; ZSWatch; Comments:; Sheet Title:; File Name:; Dock-HW; ZSWatch Dock; Company:; RELEASED; Variant:; Board Name:; ZSWatch-Dock.kicad_pcb; Daniel Kampert; Designer:; Project Name:; Date:; Revision:

Bottom Fabrication (Scale 1:1)

# Drill Drawing L1 - L4 (Scale 1:1)

Git; Hash:; ZSWatch; Comments:; Drill Drawing (L1 - L4); Sheet Title:; File Name:; Dock-HW; ZSWatch Dock; Company:; RELEASED; Variant:; Board Name:; ZSWatch-Dock.kicad_pcb; Daniel Kampert; Designer:; Project Name:; Date:; Revision:

# Drill Drawing L1 - L4 (Scale 1:1)

Git; Hash:; ZSWatch; Comments:; Drill Drawing (L1 - L4); Sheet Title:; File Name:; Dock-HW; ZSWatch Dock; Company:; RELEASED; Variant:; Board Name:; ZSWatch-Dock.kicad_pcb; Daniel Kampert; Designer:; Project Name:; Date:; Revision:

# Top Test Points (Scale 1:1)

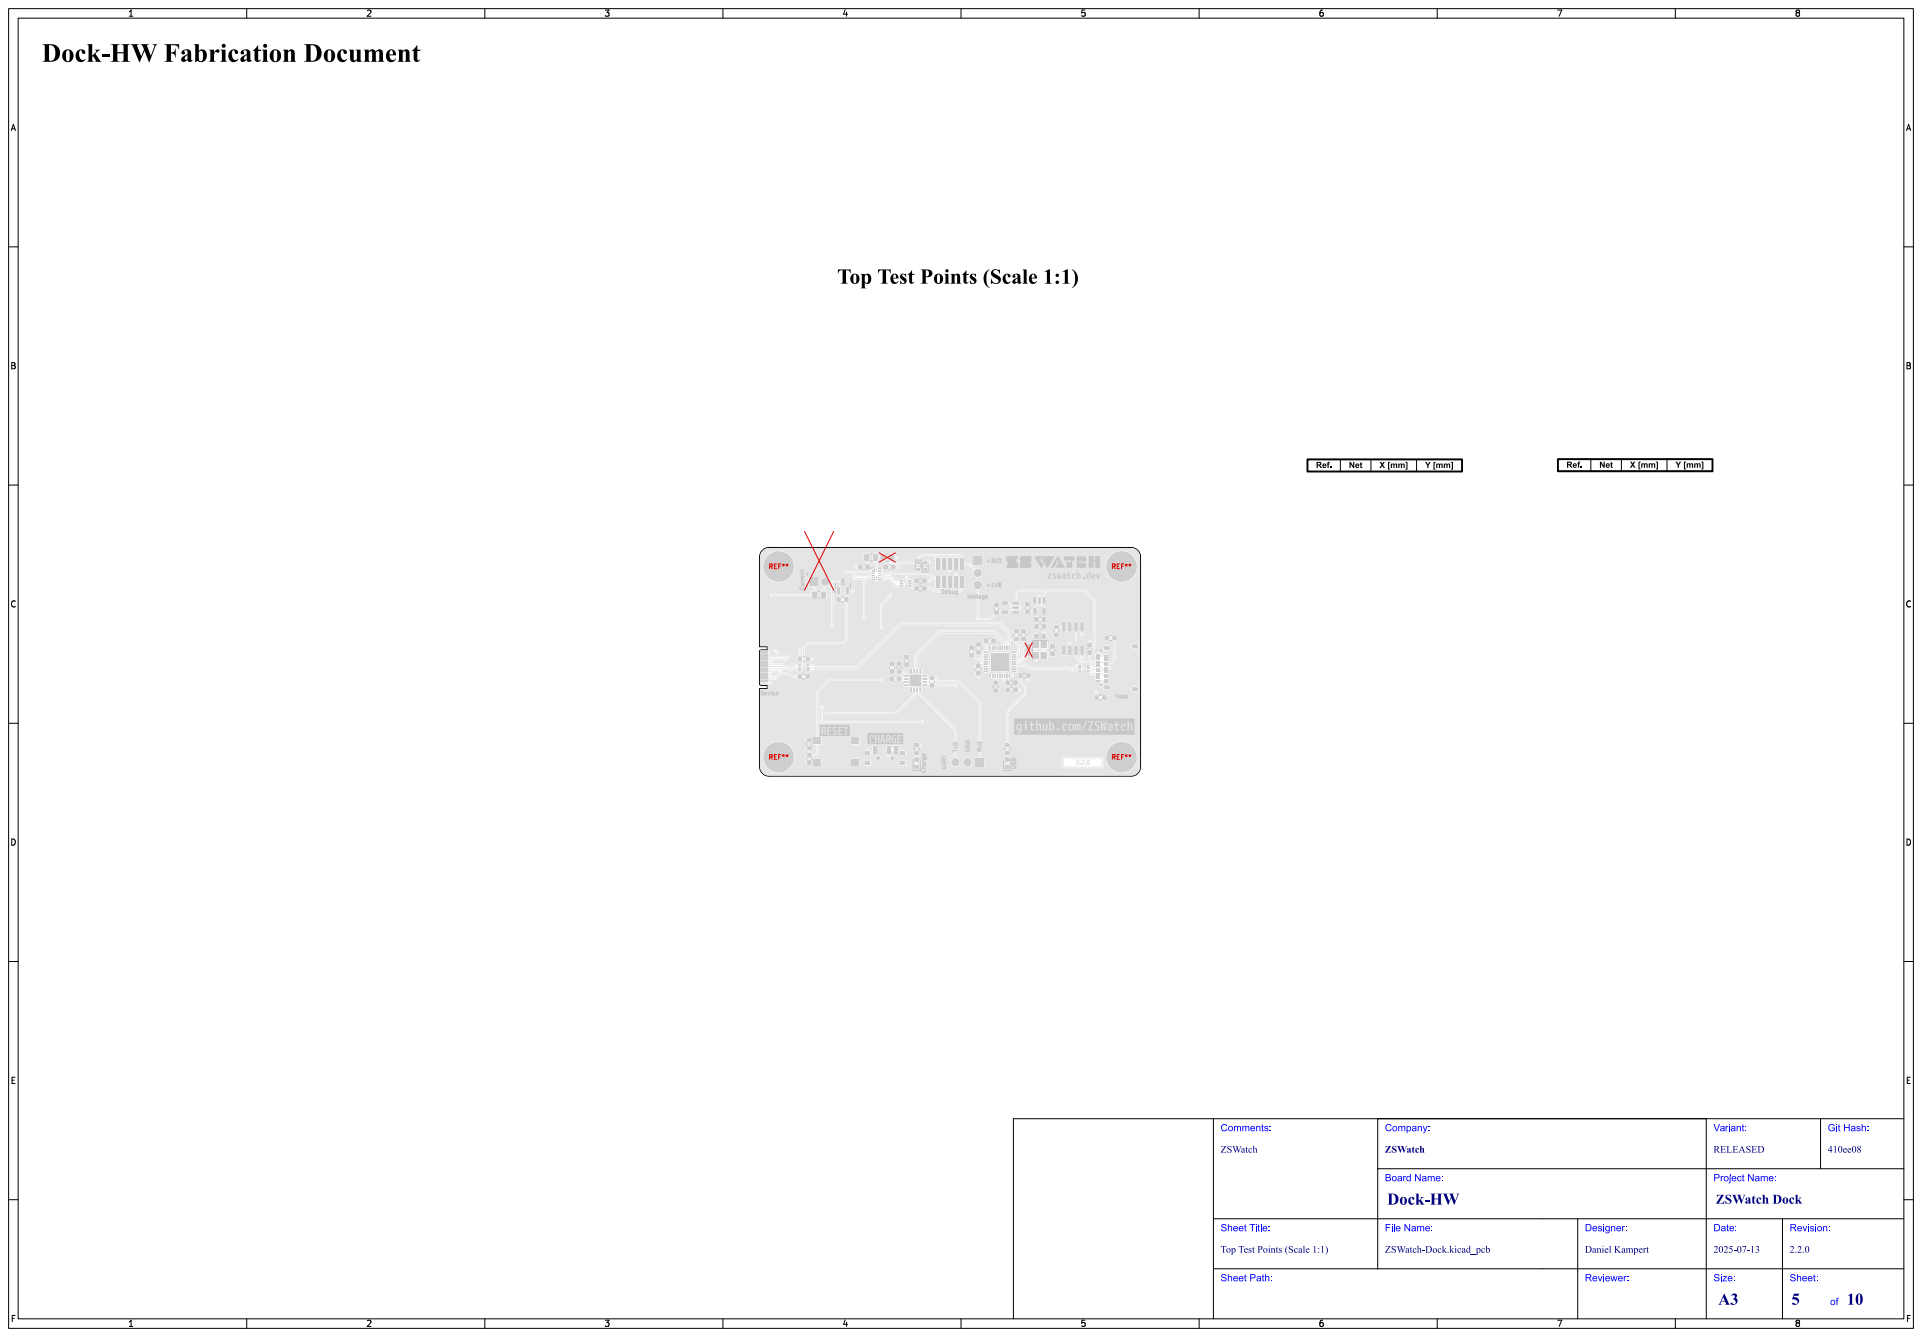
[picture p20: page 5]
Git; Hash:; ZSWatch; Comments:; Sheet Title:; File Name:; Dock-HW; ZSWatch Dock; Company:; RELEASED; Variant:; Board Name:; ZSWatch-Dock.kicad_pcb; Daniel Kampert; Designer:; Project Name:; Date:; Revision:; REF**; USB; Voltage Debug; Device; Charge; UART; Current; Host; TxD; GND; RxD

Top Test Points (Scale 1:1)

# Bottom Test Points (Scale 1:1)

Git; Hash:; ZSWatch; Comments:; Sheet Title:; File Name:; Dock-HW; ZSWatch Dock; Company:; RELEASED; Variant:; Board Name:; ZSWatch-Dock.kicad_pcb; Daniel Kampert; Designer:; Project Name:; Date:; Revision:

Bottom Test Points (Scale 1:1)

# F.Cu (Scale 1:1)

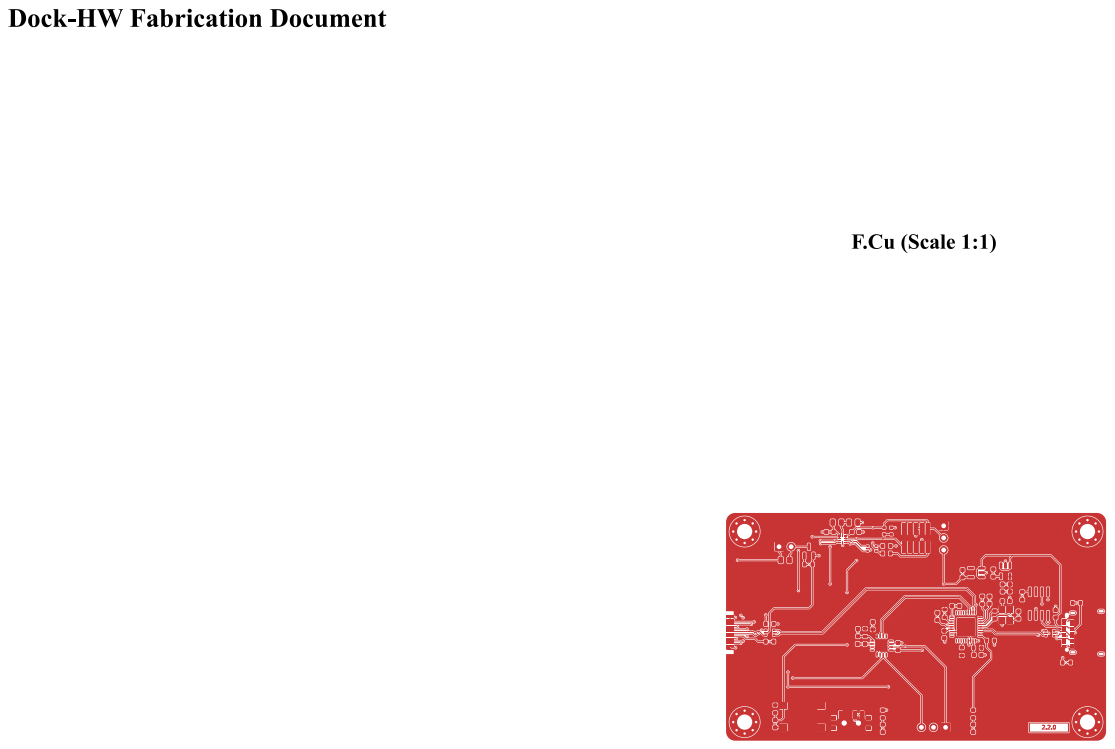
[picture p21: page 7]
Git; Hash:; ZSWatch; Comments:; F.Cu (Scale 1:1); Sheet Title:; File Name:; Dock-HW; ZSWatch Dock; Company:; RELEASED; Variant:; Board Name:; ZSWatch-Dock.kicad_pcb; Daniel Kampert; Designer:; Project Name:; Date:; Revision:

# Inner1 (Scale 1:1)

Git; Hash:; ZSWatch; Comments:; Inner1 (Scale 1:1); Sheet Title:; File Name:; Dock-HW; ZSWatch Dock; Company:; RELEASED; Variant:; Board Name:; ZSWatch-Dock.kicad_pcb; Daniel Kampert; Designer:; Project Name:; Date:; Revision:

# Inner2 (Scale 1:1)

Git; Hash:; ZSWatch; Comments:; Inner2 (Scale 1:1); Sheet Title:; File Name:; Dock-HW; ZSWatch Dock; Company:; RELEASED; Variant:; Board Name:; ZSWatch-Dock.kicad_pcb; Daniel Kampert; Designer:; Project Name:; Date:; Revision:

# B.Cu (Scale 1:1)

Git; Hash:; ZSWatch; Comments:; B.Cu (Scale 1:1); Sheet Title:; File Name:; Dock-HW; ZSWatch Dock; Company:; RELEASED; Variant:; Board Name:; ZSWatch-Dock.kicad_pcb; Daniel Kampert; Designer:; Project Name:; Date:; Revision:

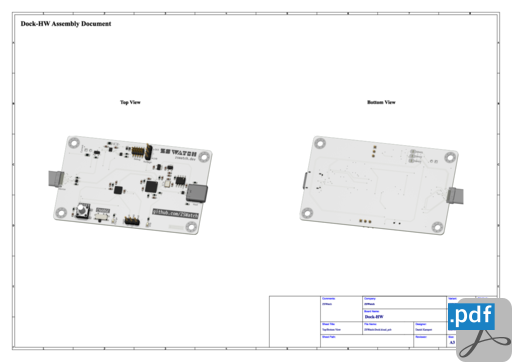
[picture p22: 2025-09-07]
production/dock-CHECKED/HTML/images/cat_pdf_assembly_ZSWatch-Dock-assembly.png

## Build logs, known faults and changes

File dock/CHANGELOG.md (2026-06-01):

# Changelog

## [Unreleased]

## [2.2.1] - 2026-06-01

**Fixed:**

-   Fix inverted Charge-Switch (#51)
-   Fix wrong reset button (#45)
-   Fix wrong pin header for SWD (#44)
-   Fix swapped UART and SWD pins for USB (#48)

**Added:**

-   Add new KiCad template (#42)
-   Add 22R series resistors for SWD lines (#52)
-   Add 0R resistors (NA) to bridge the level shifter (#54)

**Changed:**

-   Replace USB connector with edge mounted female USB (#61)
-   Replace level shifter with TXB0102 (#59)
-   Change silkscreen to white (#60)
-   Replace the USB LED with a darker one (#58)
-   Replace ESD diodes with USBLC6-2P6 (#50)
-   Change ZSWatch USB to a single sided and more stable one (#69)
-   Move Voltage REF connector a little (#72)

**Removed:**

-   Remove box around the version number (#73)

## [2.2.0] - 2025-09-18

**Fixed:**

-   Fix inverted Charge-Switch (#51)
-   Flip Rx and Tx lines for USB UART (#48)
-   Fix wrong reset button (#45)
-   Fix wrong pin header for SWD (#44)

**Added:**

-   Add new KiCad template (#42)
-   Add 22R series resistors for SWD lines (#52)
-   Add 0R resistors (NA) to bridge the level shifter (#54)

**Changed:**

-   Replace USB connector with edge mounted female USB (#61)
-   Replace level shifter with TXB0102 (#59)
-   Change silkscreen to white (#60)
-   Replace the USB LED with a darker one (#58)
-   Replace ESD diodes with USBLC6-2P6 (#50)

[Unreleased]: https://github.com/ZSWatch/Dock-HW/compare/2.2.1...HEAD

[2.2.1]: https://github.com/ZSWatch/Dock-HW/compare/2.2.0...2.2.1

[2.2.0]: https://github.com/ZSWatch/Dock-HW/compare/dfc9fc7a816f1bca3053179d156d73cdca270ef3...2.2.0

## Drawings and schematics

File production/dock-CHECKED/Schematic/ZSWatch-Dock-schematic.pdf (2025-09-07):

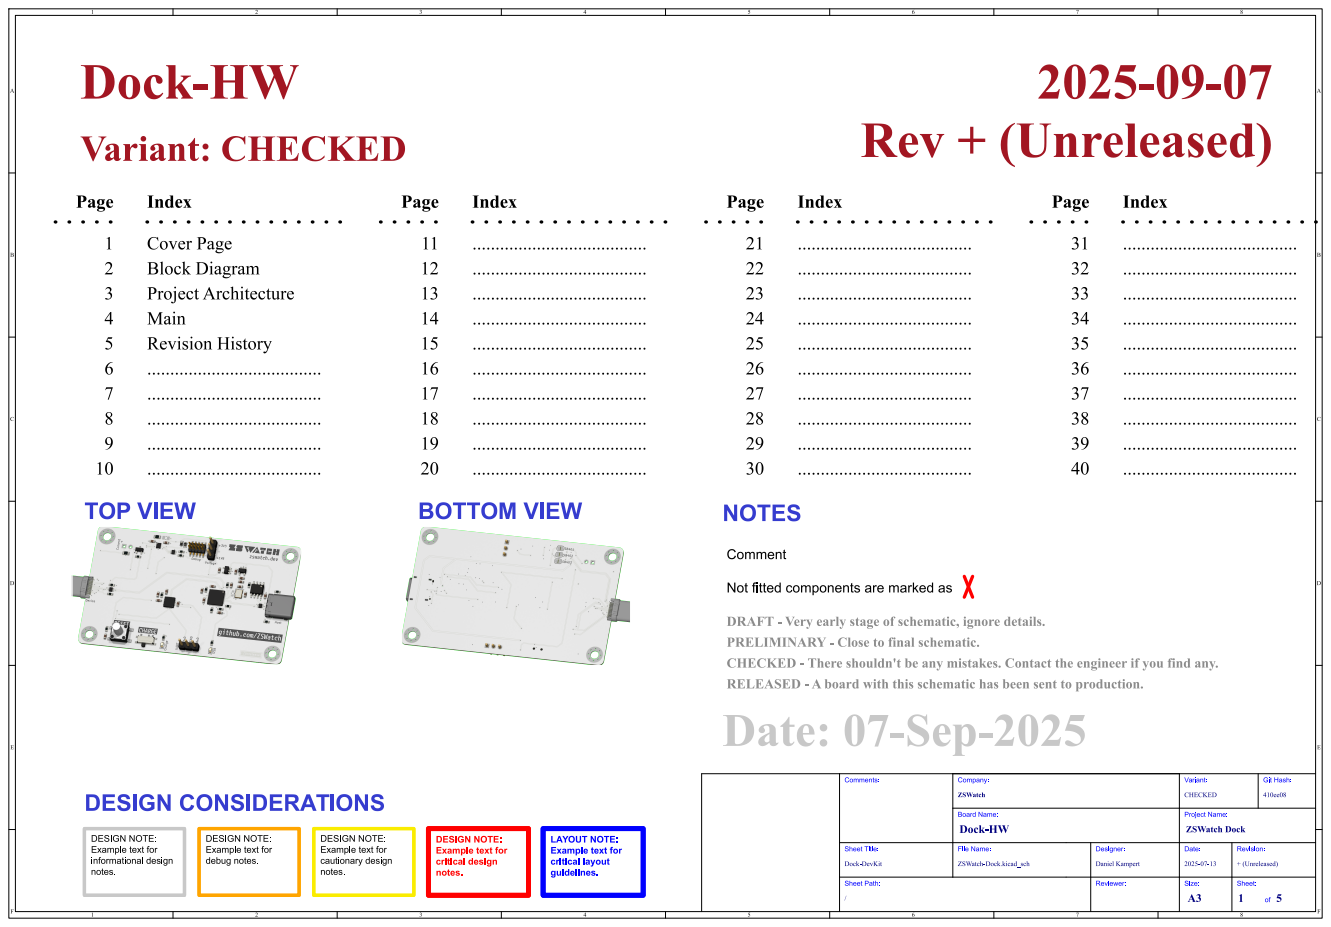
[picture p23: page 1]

Not fitted components are marked as

DRAFT - Veryearlystageof schematic,ignoredetails.

CHECKED - Thereshouldn'tbeanymistakes.Contacttheengineerif youfindany.
RELEASED - A boardwiththisschematichasbeensenttoproduction.

Revision: + (Unreleased) Date: Project Name: 2025-07-13 Reviewer: Designer:

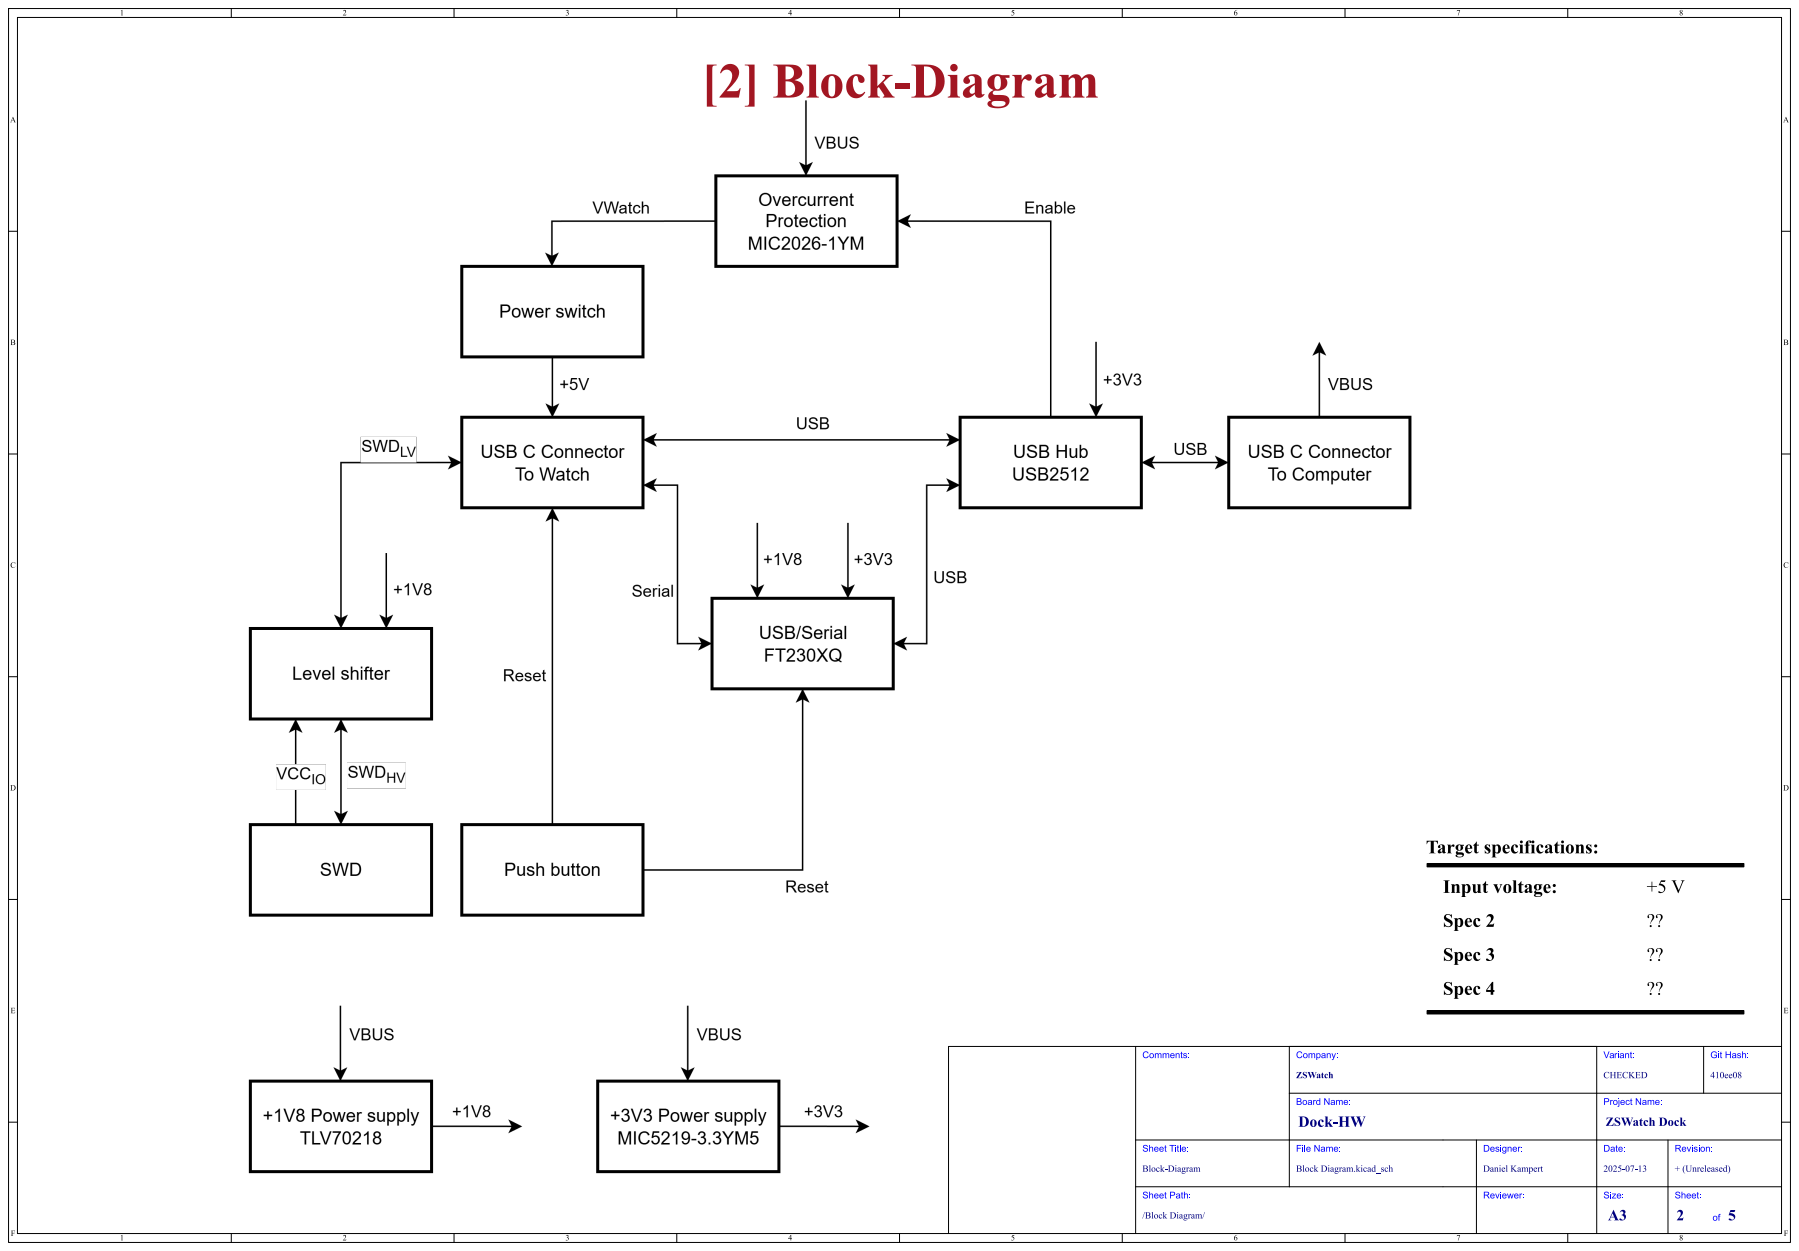
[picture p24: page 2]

/Block Diagram/ Sheet Path: Block-Diagram

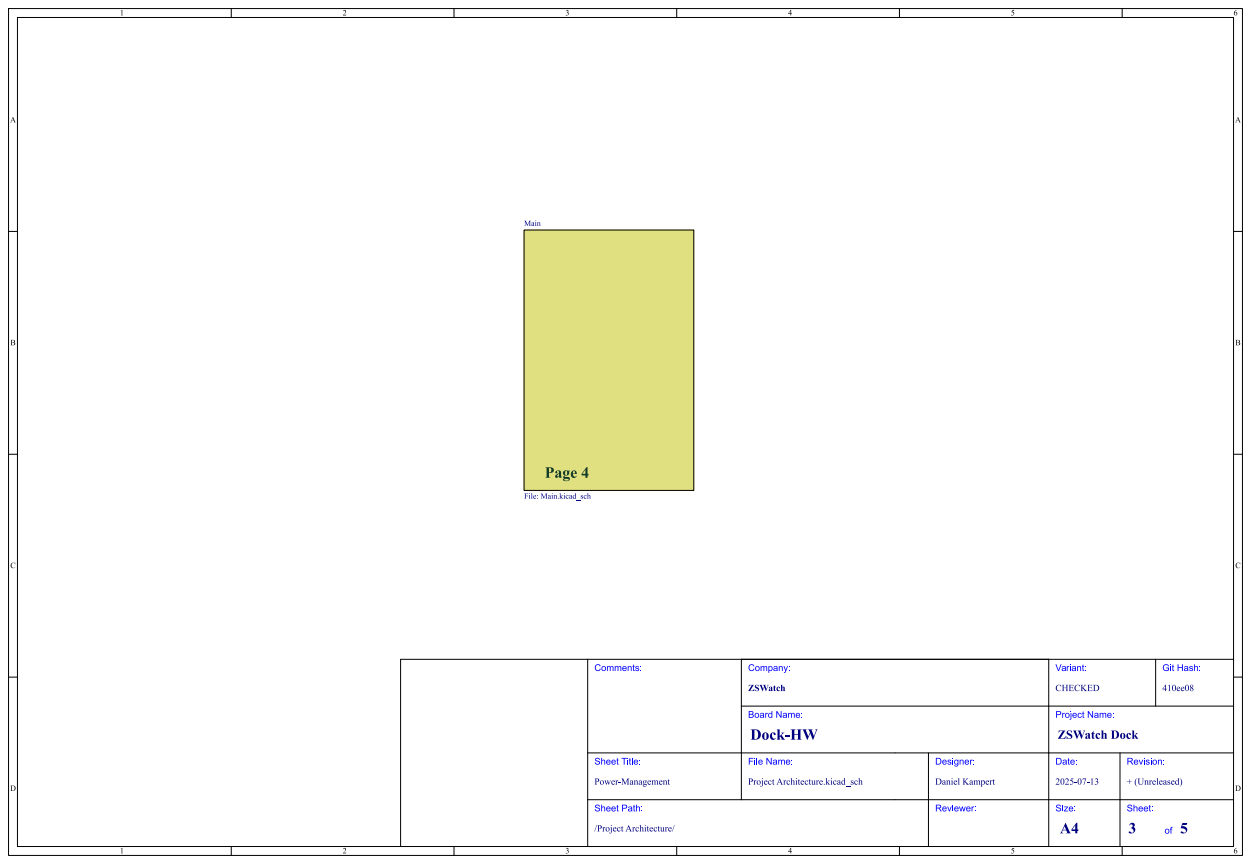
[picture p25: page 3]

Revision: + (Unreleased) Date: Project Name: 2025-07-13 Reviewer: Designer:

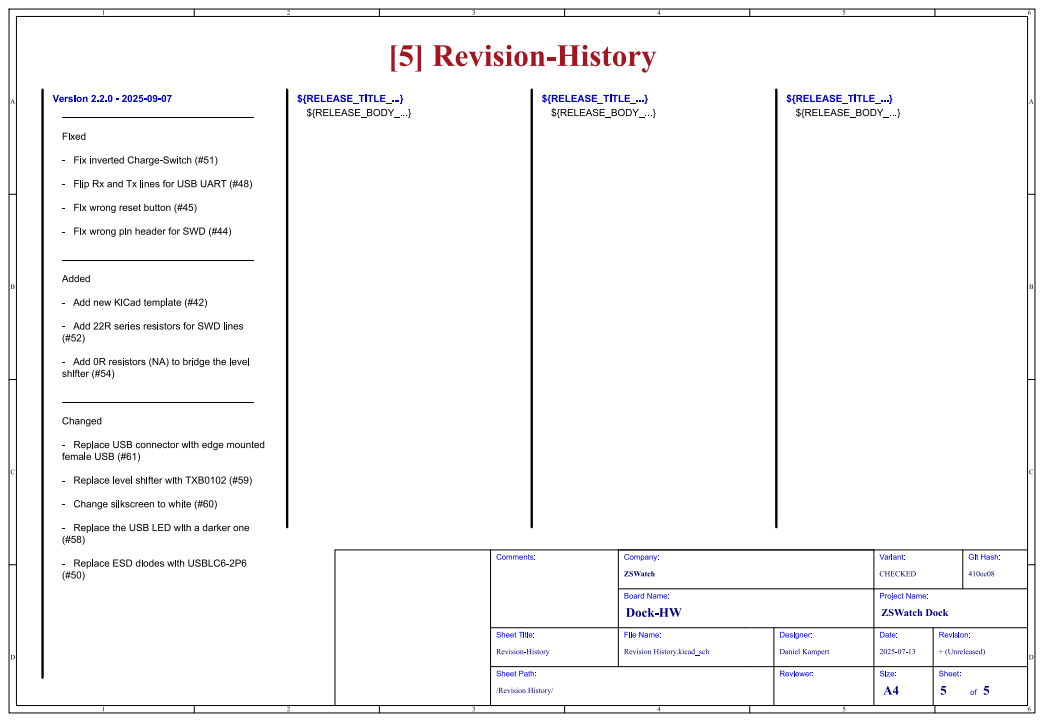
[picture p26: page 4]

- Fix inverted Charge-Switch (#51)

- Flip Rx and Tx lines for USB UART (#48)

- Fix wrong reset button (#45)

- Fix wrong pin header for SWD (#44) ___________________________________ Added

- Add new KiCad template (#42)

- Add 22R series resistors for SWD lines

- Add 0R resistors (NA) to bridge the level
shifter (#54) ___________________________________ Changed

- Replace USB connector with edge mounted
female USB (#61)

- Replace level shifter with TXB0102 (#59)

- Change silkscreen to white (#60)

- Replace the USB LED with a darker one

- Replace ESD diodes with USBLC6-2P6

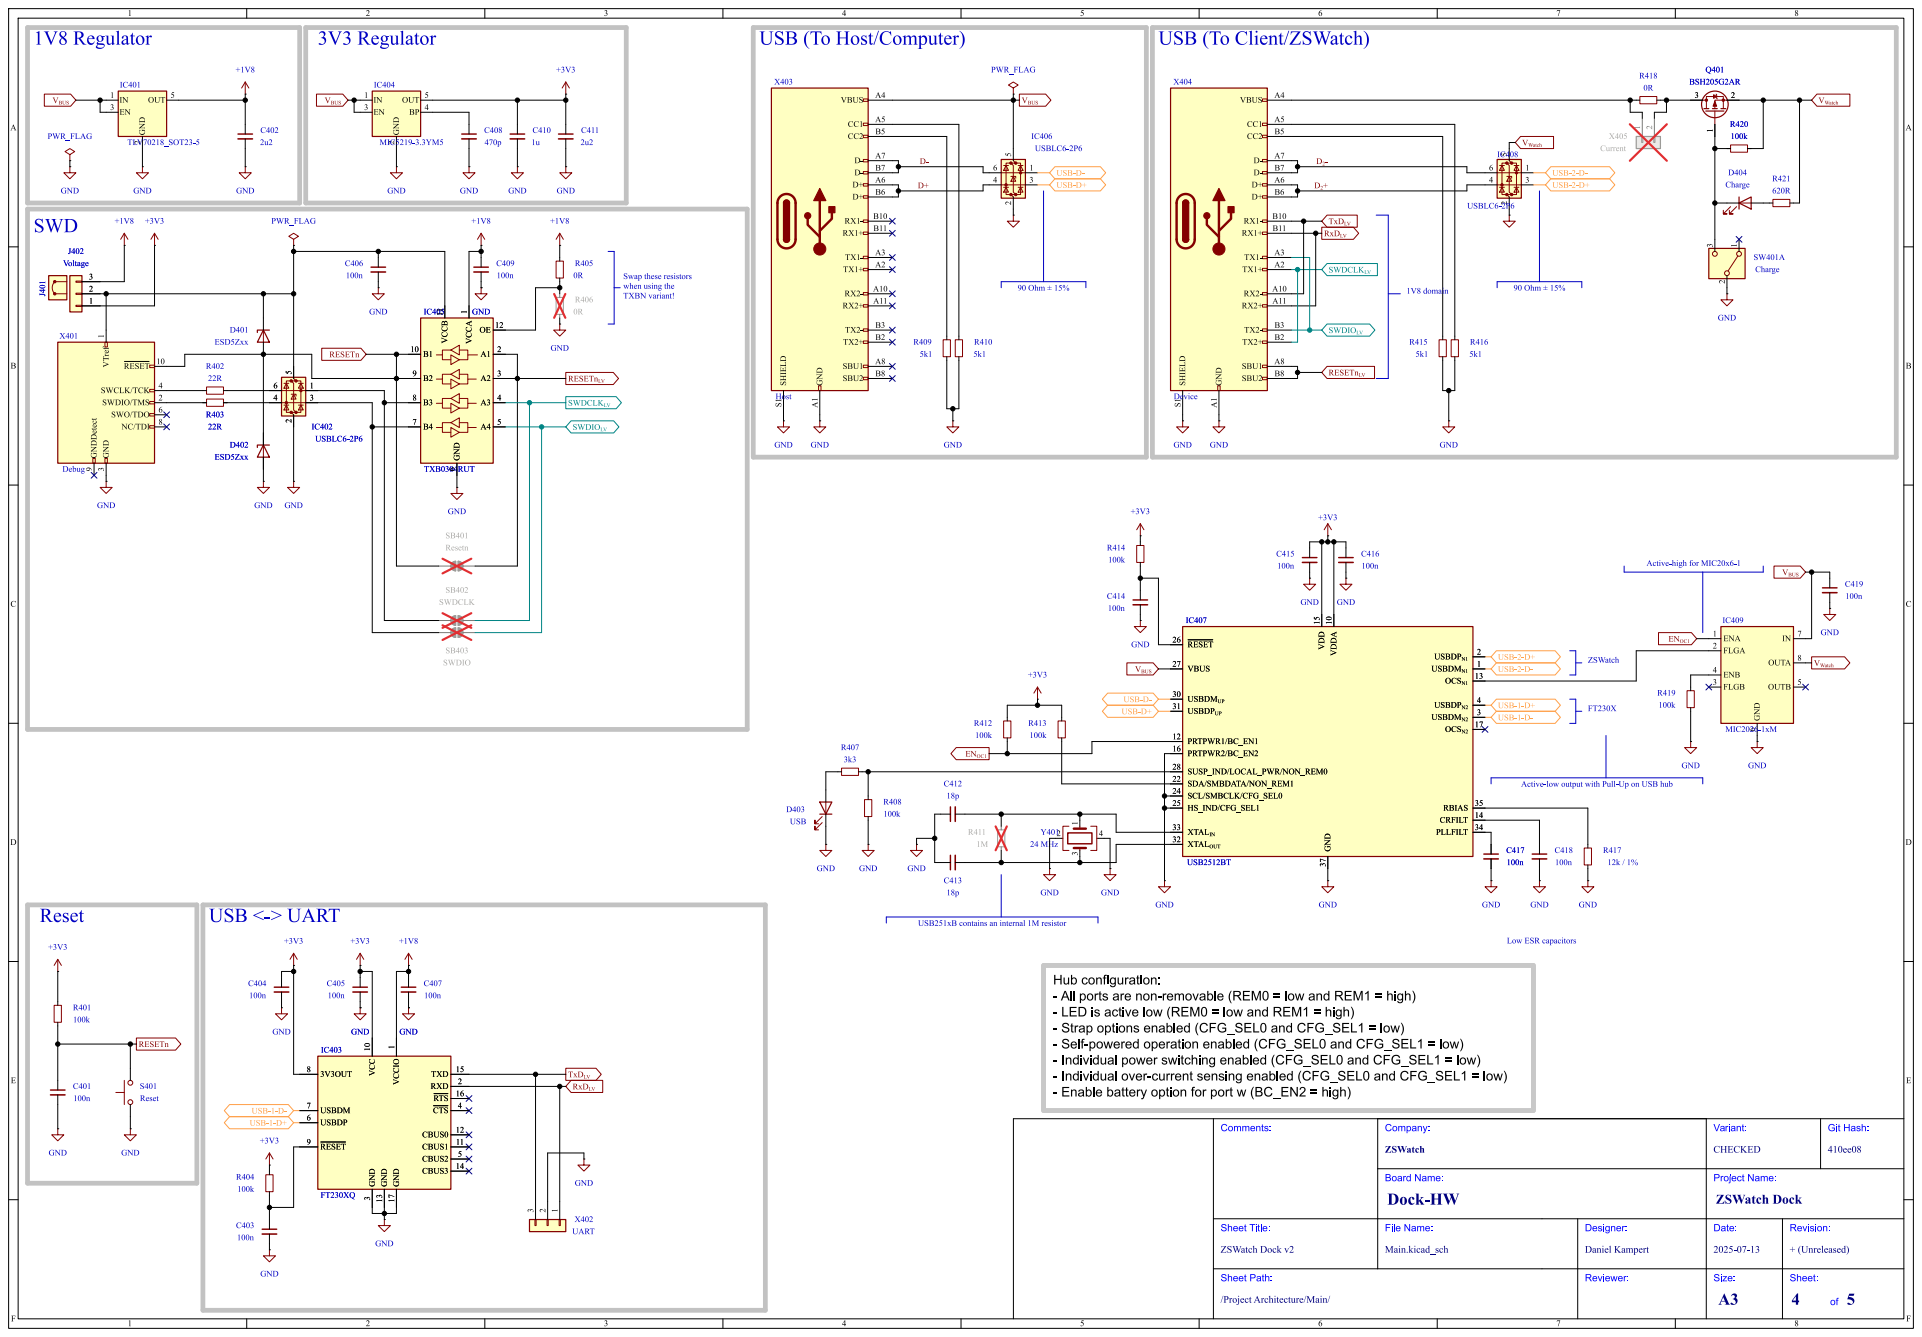
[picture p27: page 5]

Low ESRcapacitors ZSWatch USB(ToClient/ZSWatch)

3 ~{RESET}10 SWCLK/TCK 4 SWDIO/TMS 2 SWO/TDO 6 NC/TDI 8 X401 Debug J401 PWR_FLAG

- LED is active low (REM0 = low and REM1 = high)
- Strap options enabled (CFG_SEL0 and CFG_SEL1 = low)
- Self-powered operation enabled (CFG_SEL0 and CFG_SEL1 = low)
- Individual power switching enabled (CFG_SEL0 and CFG_SEL1 = low)
- Individual over-current sensing enabled (CFG_SEL0 and CFG_SEL1 = low)
- Enable battery option for port w (BC_EN2 = high)

1 GND 17 TXD 15 RXD 2 ~{RTS}16 ~{CTS}4 CBUS0 12 CBUS1 11 CBUS2 5 CBUS3 14 GND GND

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

Revision: + (Unreleased) Date: Project Name: 2025-07-13 Reviewer: Designer:

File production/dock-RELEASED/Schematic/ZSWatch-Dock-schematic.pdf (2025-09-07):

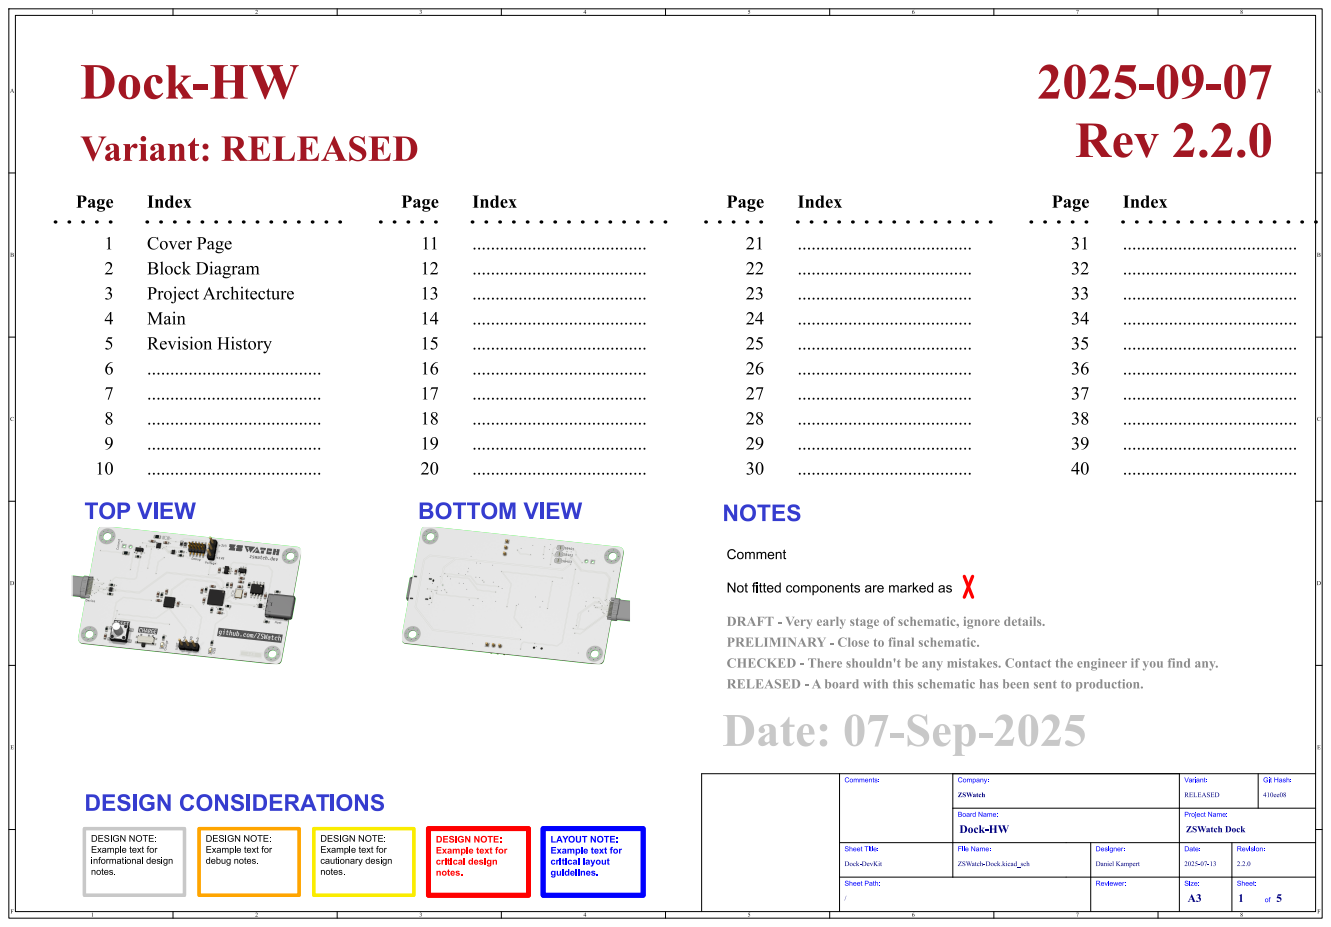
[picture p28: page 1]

Not fitted components are marked as

DRAFT - Veryearlystageof schematic,ignoredetails.

Revision: 2.2.0 Date: Project Name: 2025-07-13 Reviewer: Designer:

File: Project Architecture.kicad_sch DESIGN NOTE:
Example text for
informational design
notes.

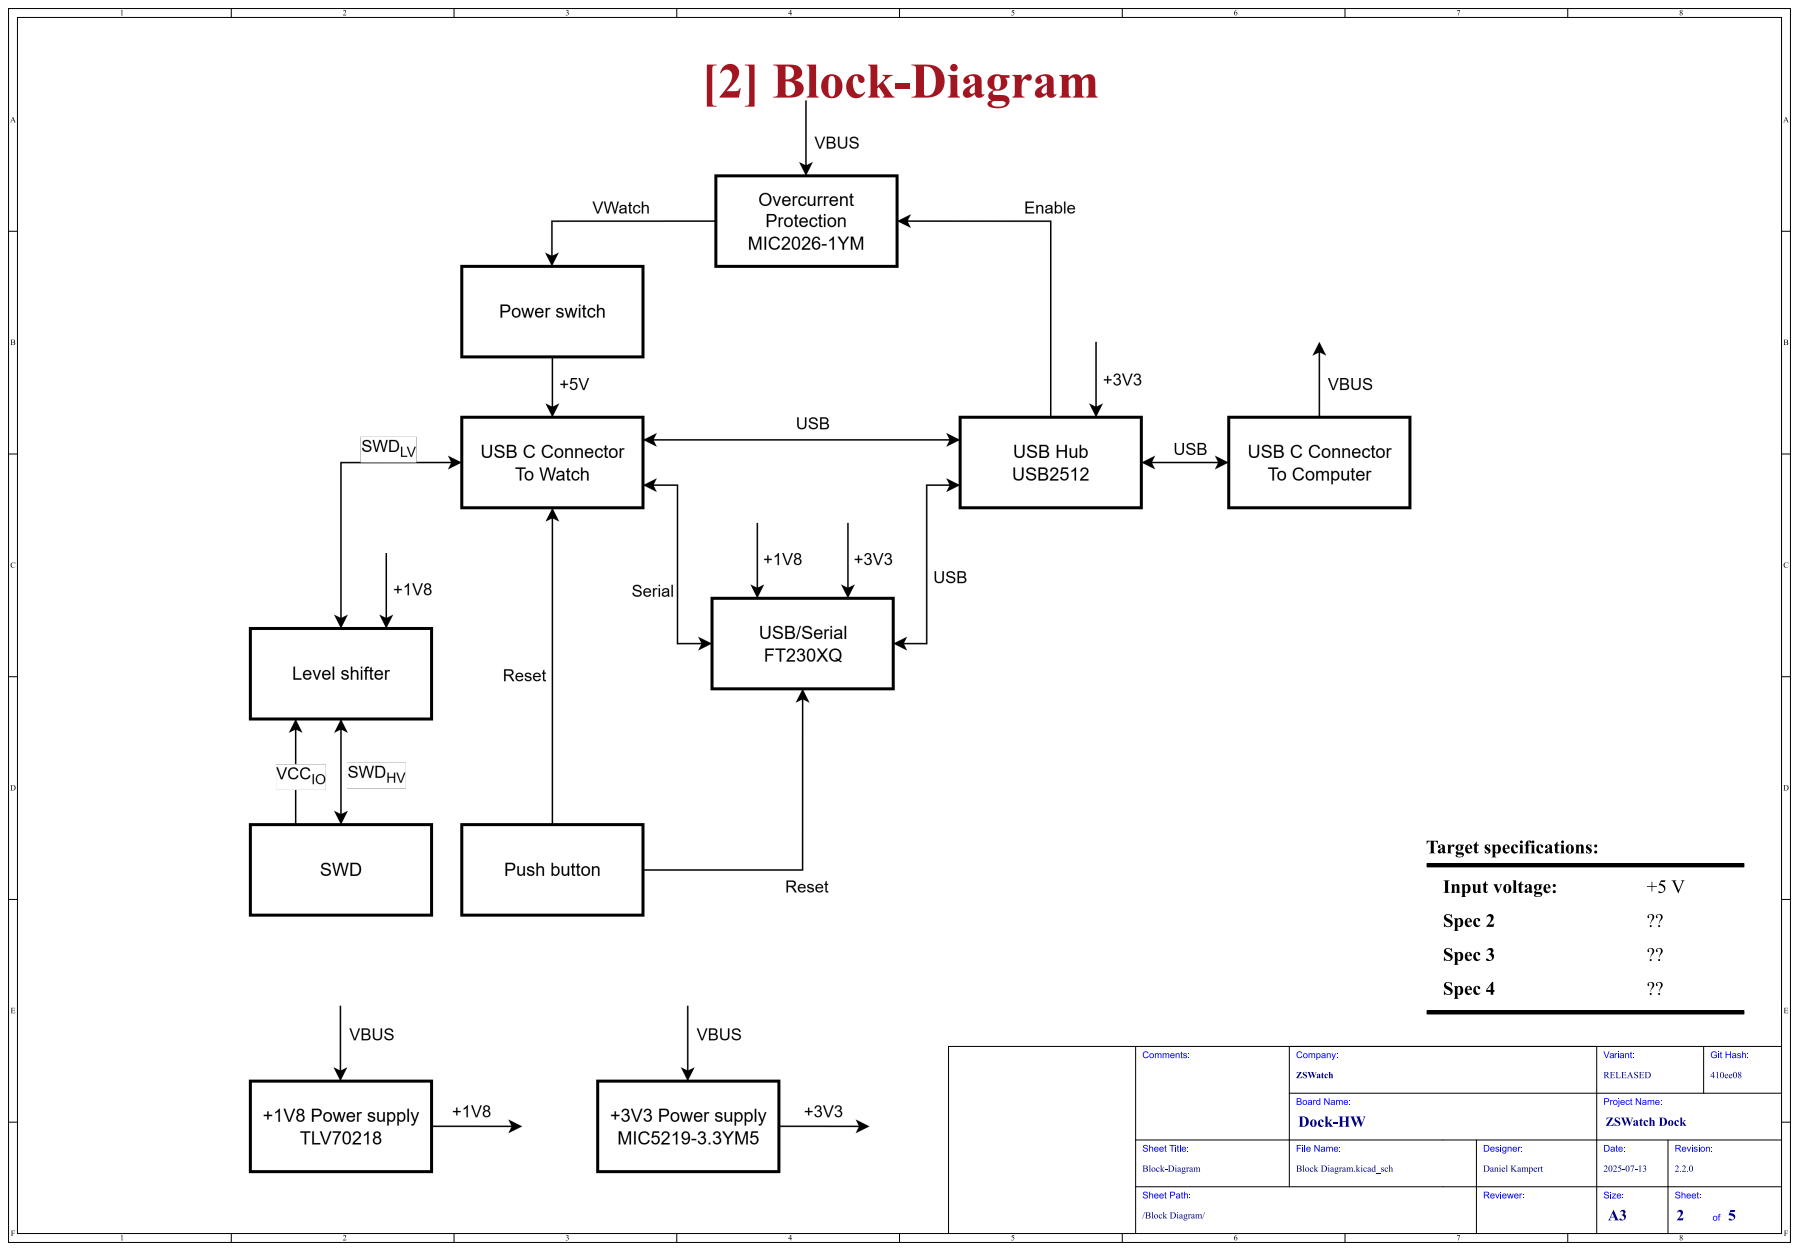
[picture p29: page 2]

/Block Diagram/ Sheet Path: Block-Diagram

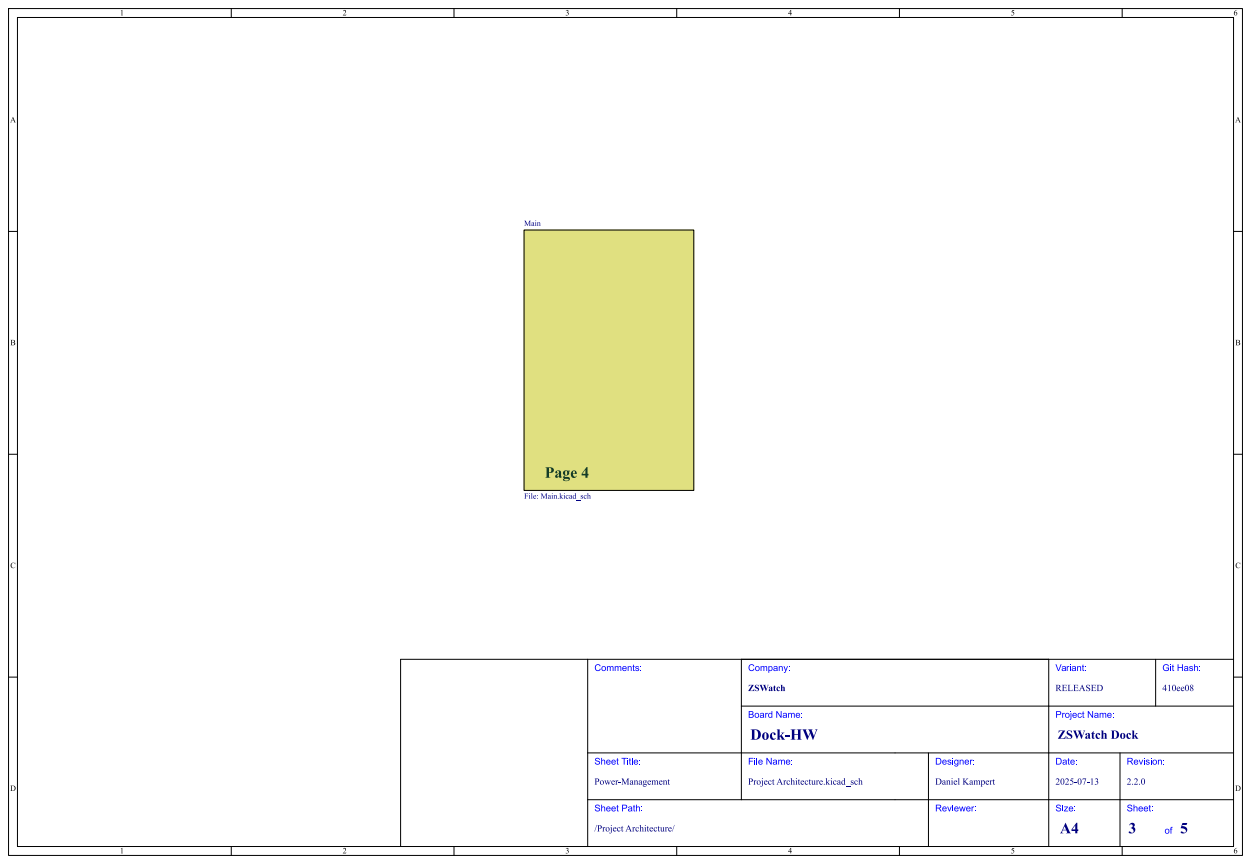
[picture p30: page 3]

Revision: 2.2.0 Date: Project Name: 2025-07-13 Reviewer: Designer:

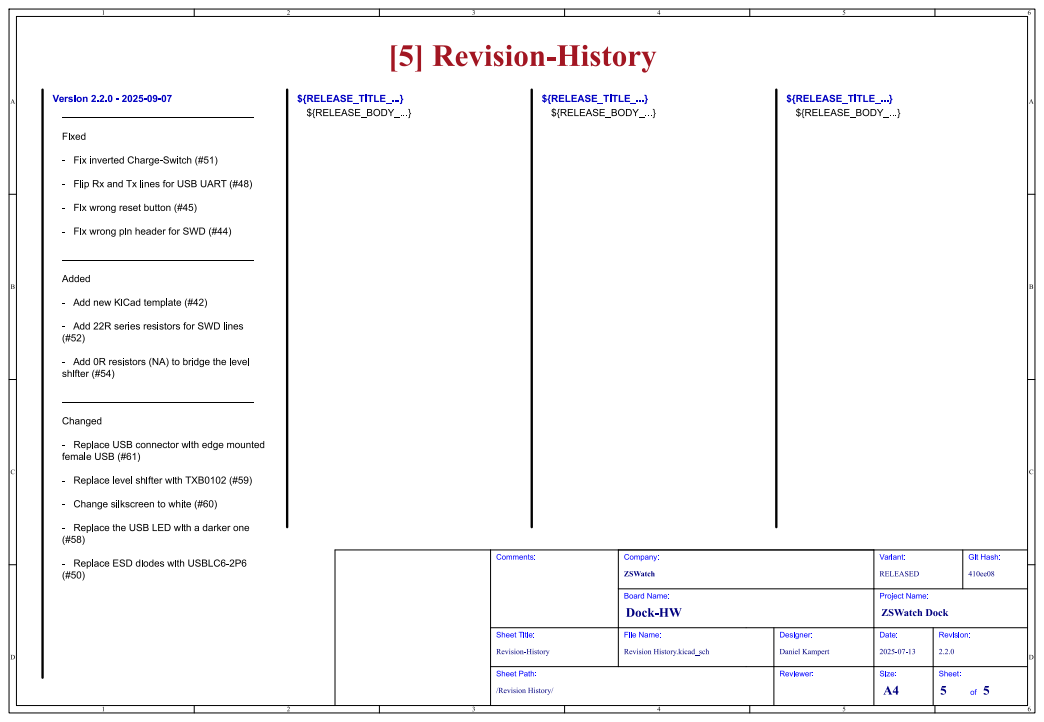
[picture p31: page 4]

- Fix inverted Charge-Switch (#51)

- Flip Rx and Tx lines for USB UART (#48)

- Fix wrong reset button (#45)

- Fix wrong pin header for SWD (#44) ___________________________________ Added

- Add new KiCad template (#42)

- Add 22R series resistors for SWD lines

- Add 0R resistors (NA) to bridge the level
shifter (#54) ___________________________________ Changed

- Replace USB connector with edge mounted
female USB (#61)

- Replace level shifter with TXB0102 (#59)

- Change silkscreen to white (#60)

- Replace the USB LED with a darker one

- Replace ESD diodes with USBLC6-2P6

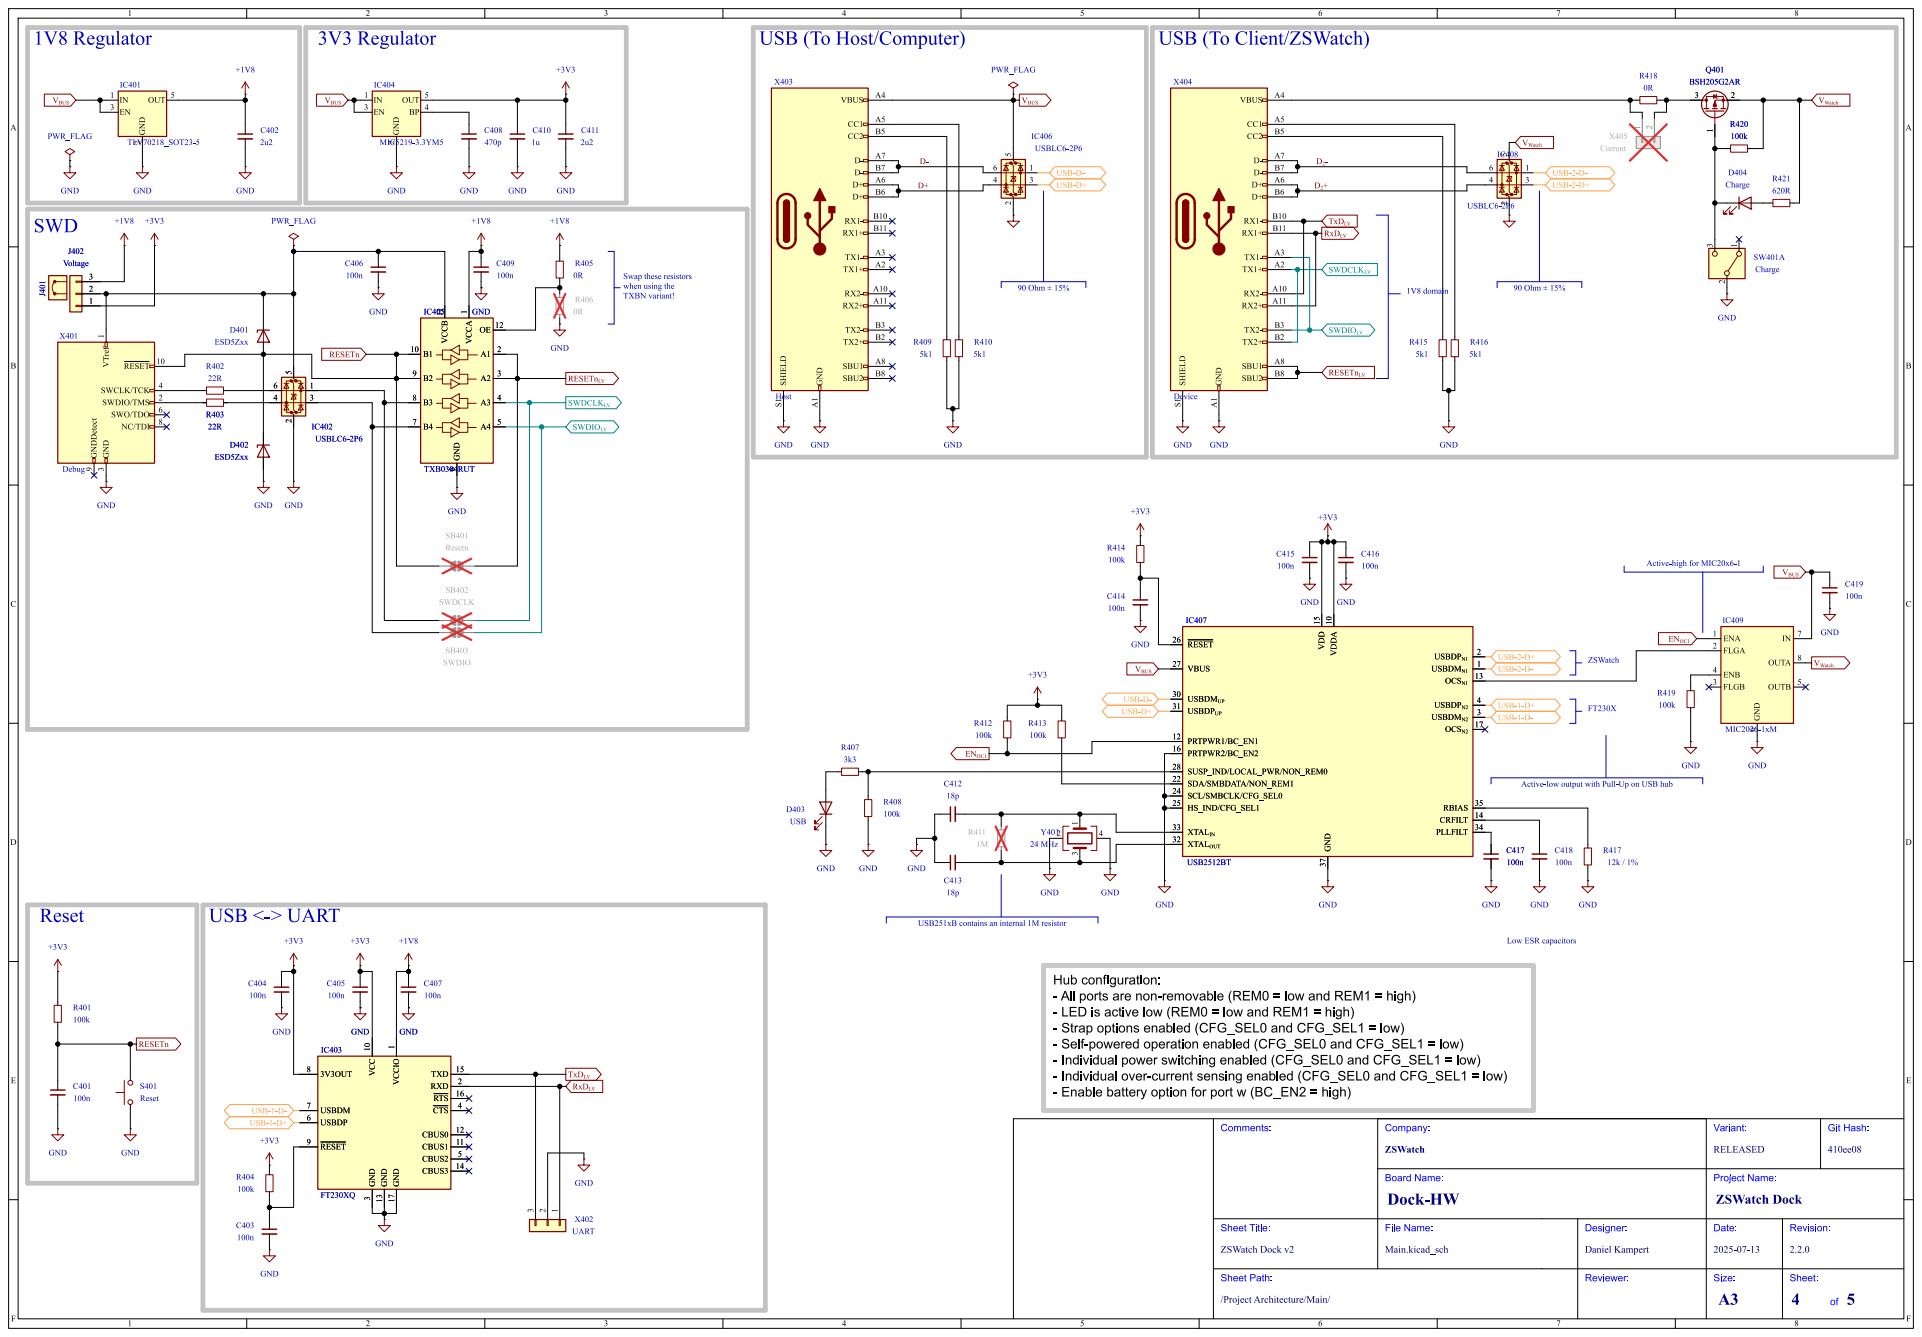
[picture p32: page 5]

Low ESRcapacitors ZSWatch USB(ToClient/ZSWatch)

3 ~{RESET}10 SWCLK/TCK 4 SWDIO/TMS 2 SWO/TDO 6 NC/TDI 8 X401 Debug J401 PWR_FLAG

- LED is active low (REM0 = low and REM1 = high)
- Strap options enabled (CFG_SEL0 and CFG_SEL1 = low)
- Self-powered operation enabled (CFG_SEL0 and CFG_SEL1 = low)
- Individual power switching enabled (CFG_SEL0 and CFG_SEL1 = low)
- Individual over-current sensing enabled (CFG_SEL0 and CFG_SEL1 = low)
- Enable battery option for port w (BC_EN2 = high)

1 GND 17 TXD 15 RXD 2 ~{RTS}16 ~{CTS}4 CBUS0 12 CBUS1 11 CBUS2 5 CBUS3 14 GND GND

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

Revision: 2.2.0 Date: Project Name: 2025-07-13 Reviewer: Designer:

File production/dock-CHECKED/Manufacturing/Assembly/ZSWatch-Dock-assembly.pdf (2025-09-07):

# Dock-HW Assembly Document

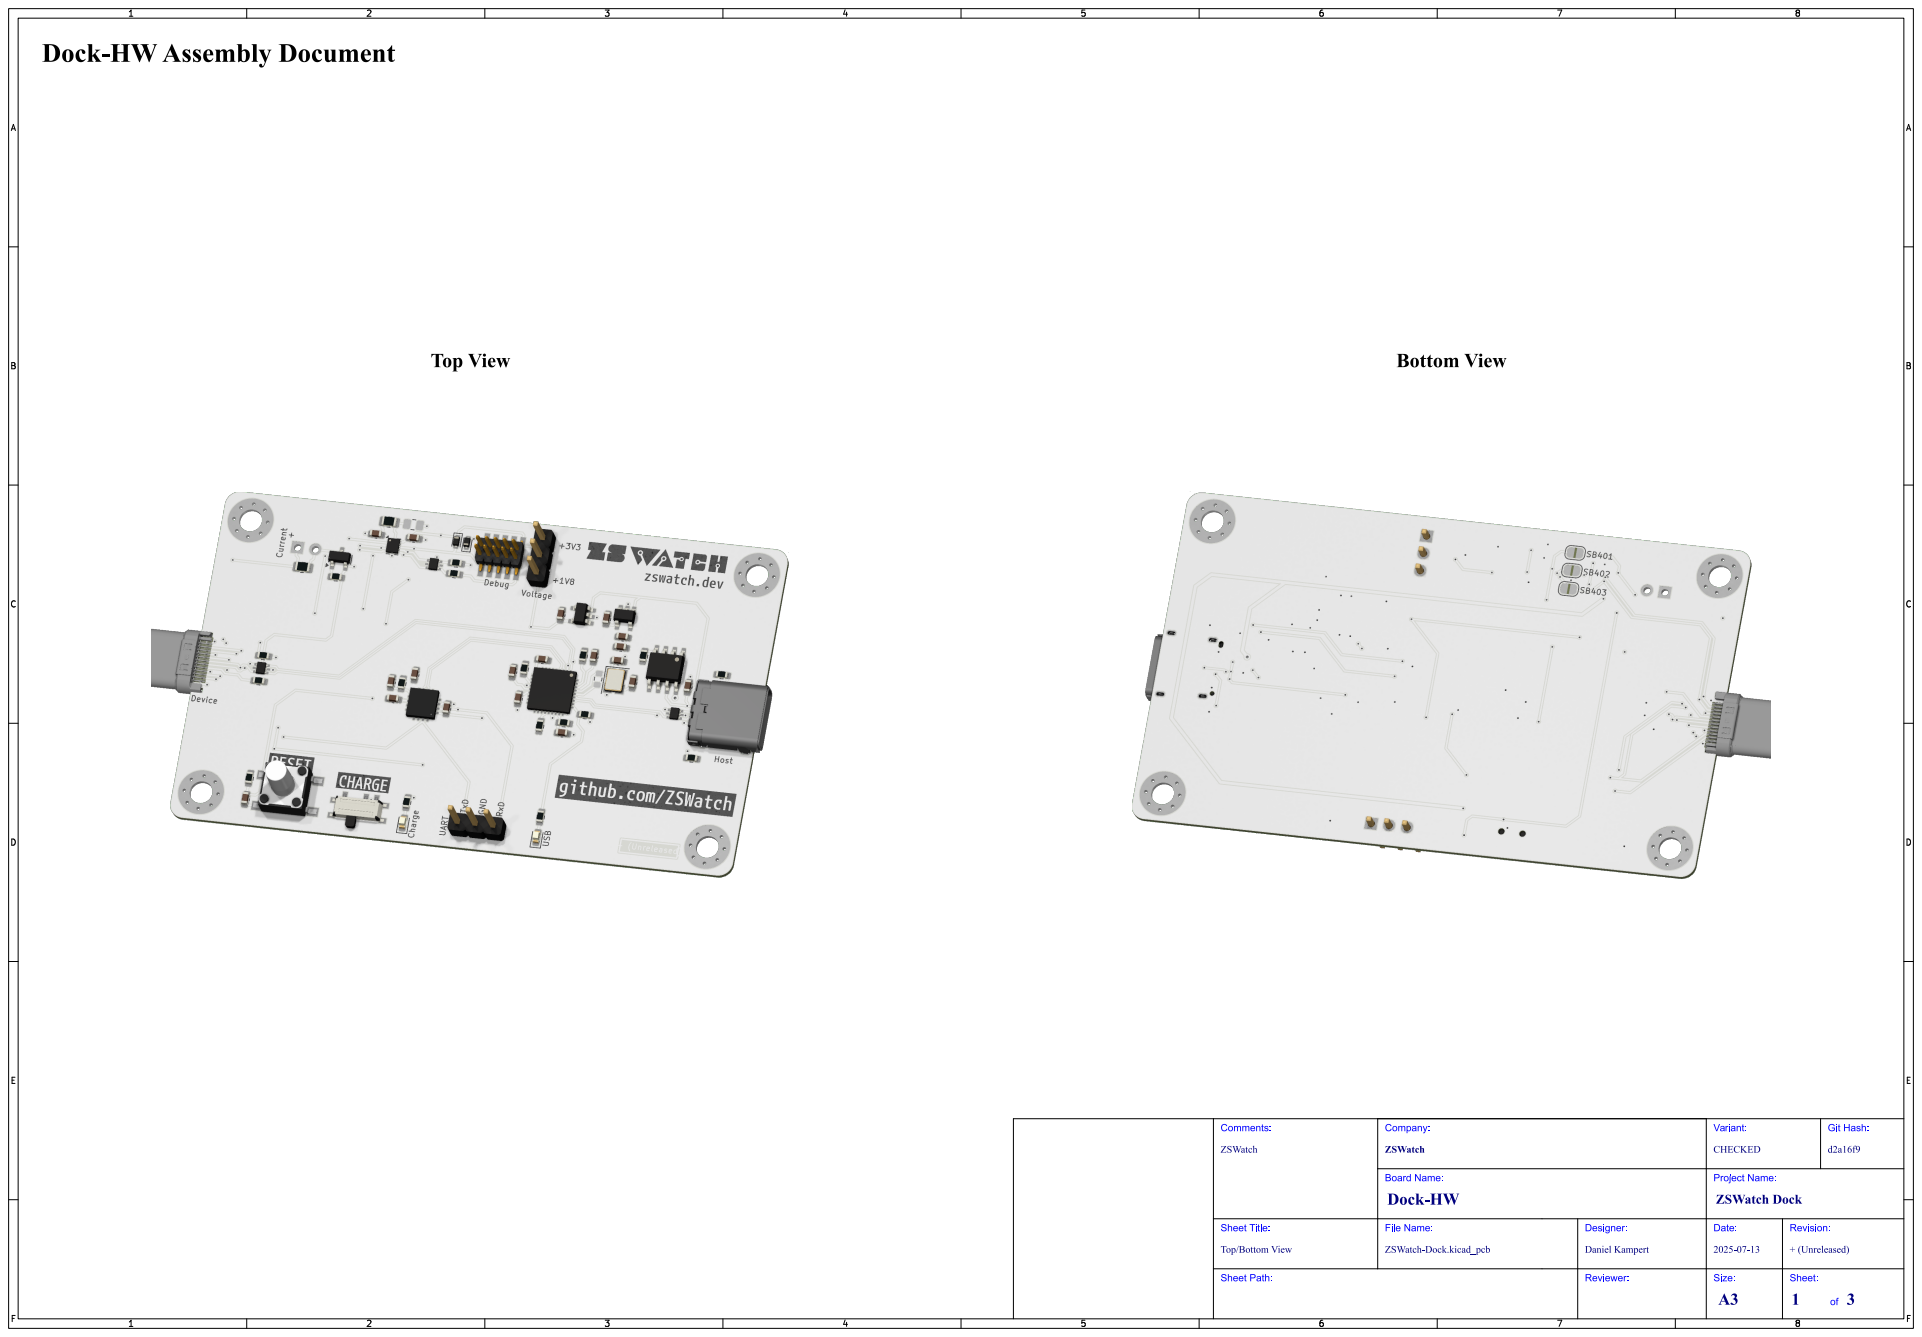
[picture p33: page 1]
Git; Hash:; ZSWatch; Comments:; Sheet Path:; Sheet Title:; File Name:; Dock-HW; ZSWatch Dock; Company:; CHECKED; Variant:; Board Name:; ZSWatch-Dock.kicad_pcb; Daniel Kampert; Designer:; Reviewer:; Project Name:; Date:; + (Unreleased); Revision:; Size:; Sheet:; 8 PCB Edge

Top/Bottom View

# Top Assembly (Scale 1:1)

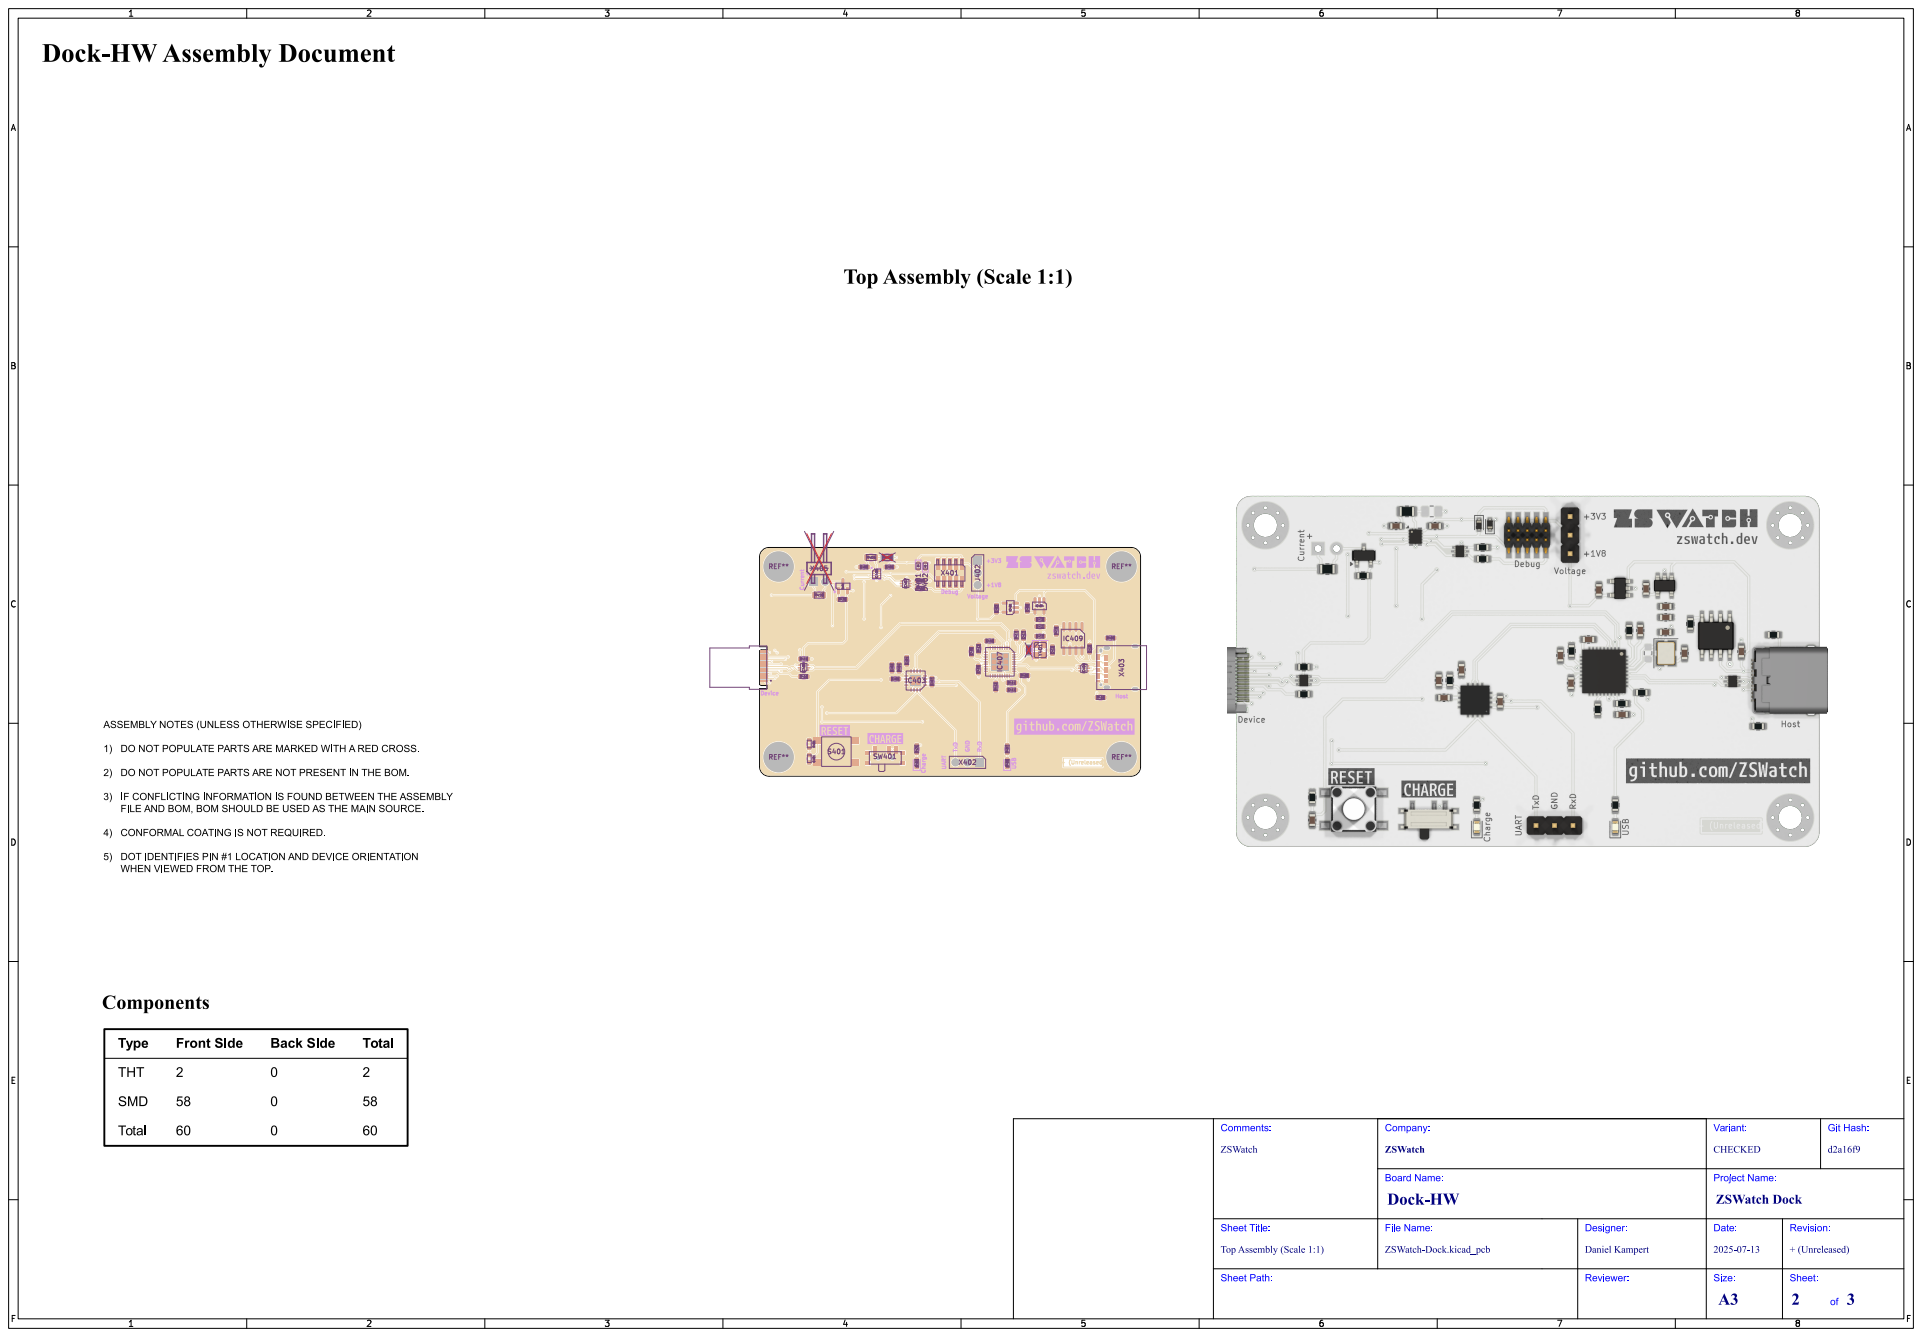
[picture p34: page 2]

# Bottom Assembly (Scale 1:1)

Git; Hash:; ZSWatch; Comments:; Sheet Title:; File Name:; Dock-HW; ZSWatch Dock; Company:; CHECKED; Variant:; Board Name:; ZSWatch-Dock.kicad_pcb; Daniel Kampert; Designer:; Project Name:; Date:; + (Unreleased); Revision:

Bottom Assembly (Scale 1:1)





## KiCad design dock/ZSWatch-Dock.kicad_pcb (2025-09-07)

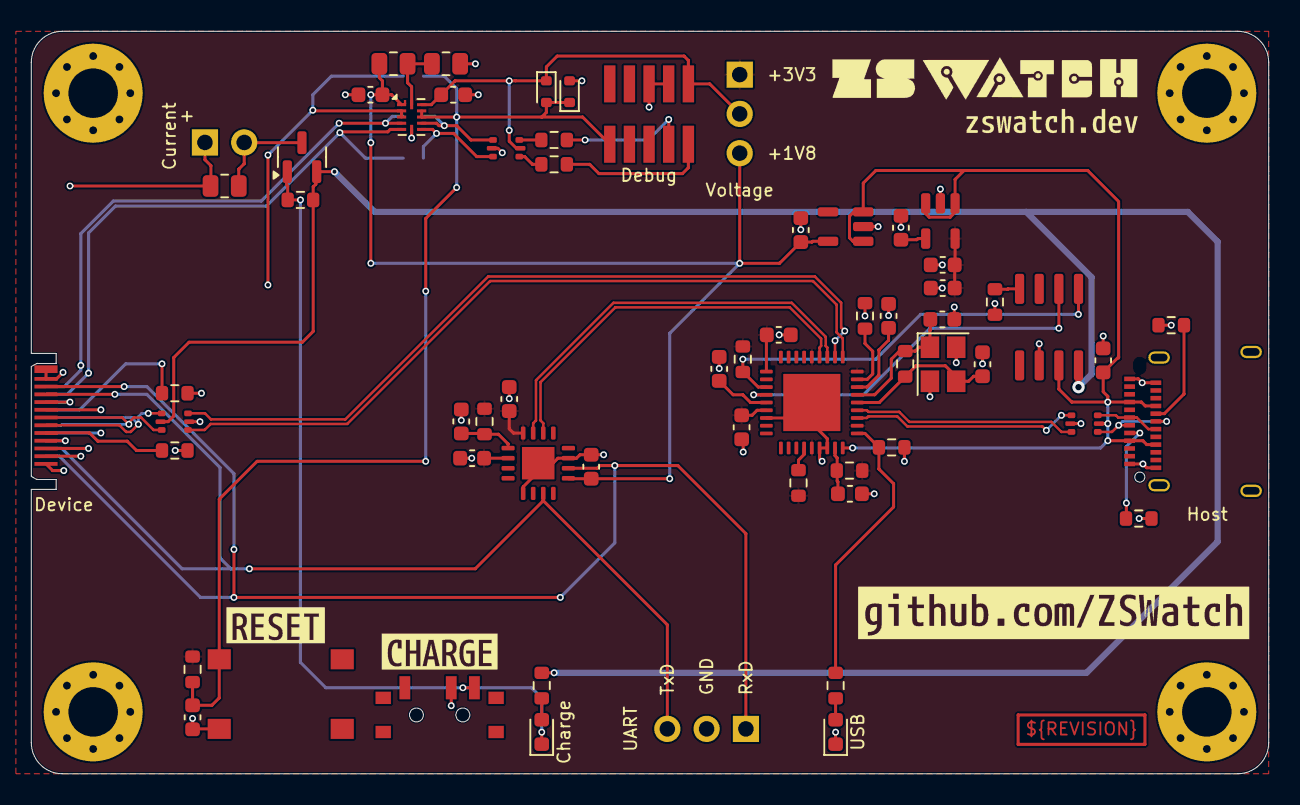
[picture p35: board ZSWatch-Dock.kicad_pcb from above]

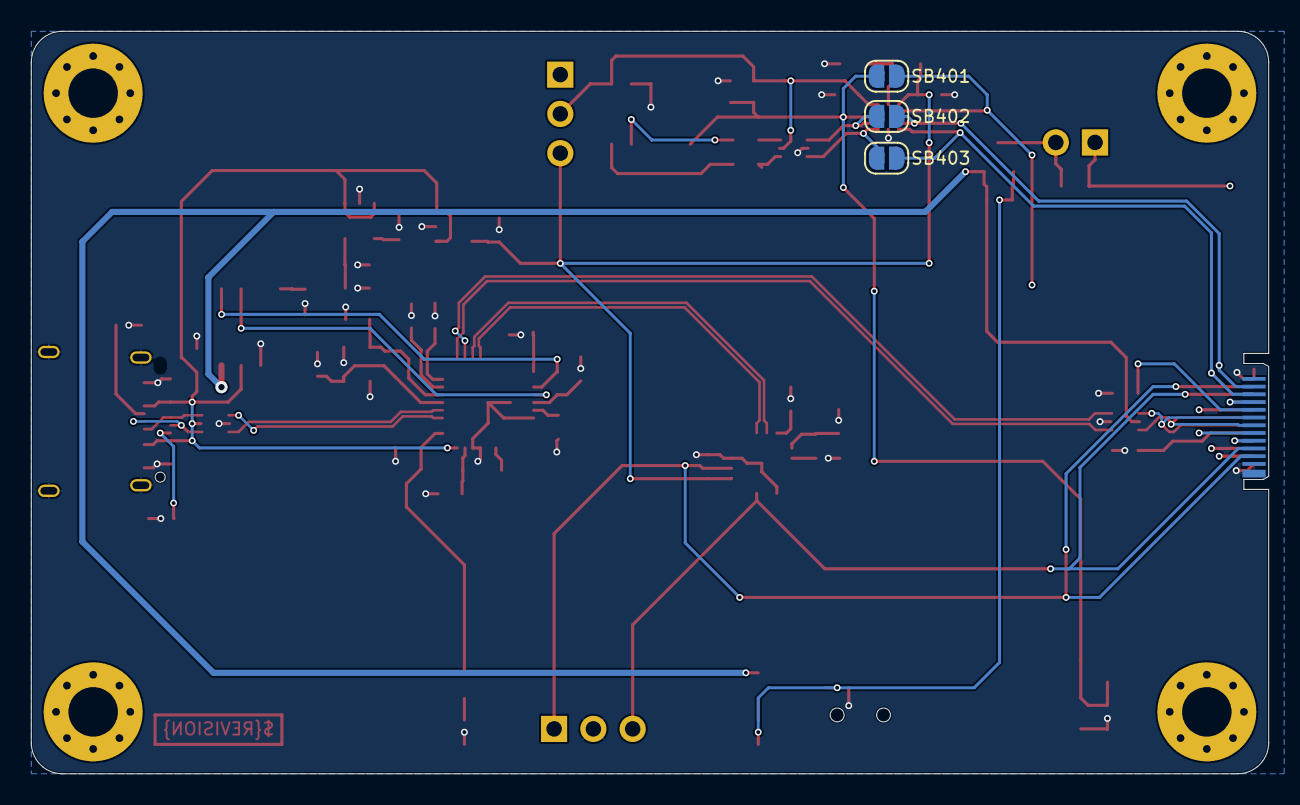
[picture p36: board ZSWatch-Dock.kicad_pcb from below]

Board: 4 copper layers, 80.0 x 48.0 mm, 70 parts (3 on the bottom side), 51 nets.

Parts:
C401, C403, C404, C405, C406, C407, C409, C414, C415, C416, C417, C418, C419: 100n; C_0603_1608Metric
C402, C411: 2u2; C_0603_1608Metric
C408: 470p; C_0603_1608Metric
C410: 1u; C_0603_1608Metric
C412, C413: 18p; C_0603_1608Metric
D401, D402: ESD5Zxx; D_SOD-523
D403: USB; LED_0603_1608Metric
D404: Charge; LED_0603_1608Metric
IC401: TLV70218_SOT23-5; SOT-23-5
IC402, IC406, IC408: USBLC6-2P6; SOT-666
IC403: FT230XQ; QFN-16-1EP_4x4mm_P0.65mm_EP2.1x2.1mm
IC404: MIC5219-3.3YM5; SOT-23-5
IC405: TXB0304RUT; Texas_R-PUQFN-N12
IC407: USB2512BT; QFN-36-1EP_6x6mm_P0.5mm_EP3.7x3.7mm
IC409: MIC2026-1xM; SOIC-8_3.9x4.9mm_P1.27mm
J402: Voltage; PinHeader_1x03_P2.54mm_Vertical
Q401: BSH205G2AR; SOT-23
R401, R404, R408, R412, R413, R414, R419, R420: 100k; R_0603_1608Metric
R402, R403: 22R; R_0603_1608Metric
R405, R406, R418: 0R; R_0805_2012Metric
R407: 3k3; R_0603_1608Metric
R409, R410, R415, R416: 5k1; R_0603_1608Metric
R411: 1M; R_0603_1608Metric
R417: 12k / 1%; R_0603_1608Metric
R421: 620R; R_0603_1608Metric
S401: Reset; WS-TASV-6x6
SB401: Resetn; SolderJumper-2_P1.3mm_Open_RoundedPad1.0x1.5mm
SB402: SWDCLK; SolderJumper-2_P1.3mm_Open_RoundedPad1.0x1.5mm
SB403: SWDIO; SolderJumper-2_P1.3mm_Open_RoundedPad1.0x1.5mm
SW401: Charge; SW_SPDT_PCM12
X401: Debug; SHF-105-01-L-D-SM-TR
X402: UART; PinHeader_1x03_P2.54mm_Vertical
X403: Host; USB_C_Receptacle_Amphenol_12401610E4-2A
X404: Device; 10133475-10001LF
X405: Current; PinHeader_1x02_P2.54mm_Horizontal
Y401: 24 MHz; Crystal_SMD_Abracon_ABM8G-4Pin_3.2x2.5mm
kibuzzard-6832BFA7: G***; kibuzzard-6832BFA7
kibuzzard-6832BFEF: G***; kibuzzard-6832BFEF
kibuzzard-68303879: G***; kibuzzard-68303879
kibuzzard-68304463: G***; kibuzzard-68304463

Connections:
+1V8: C402.1, C407.1, C409.1, IC401.5 (OUT), IC403.1 (VCCIO), IC405.1 (VCCA), J402.3, R405.1
+3V3: C404.1, C405.1, C410.1, C411.1, C415.1, C416.1, IC403.8 (3V3OUT), IC403.10 (VCC), IC404.5 (OUT), IC407.5 (VDDA), IC407.10 (VDDA), IC407.15 (VDD), IC407.23 (VDD), IC407.29 (VDDA), IC407.36 (VDDA), J402.1, R401.1, R404.1, R412.1, R413.1, R414.1
/Project Architecture/Main/D+: IC406.4 (I/O2), X403.A6 (D+), X403.B6 (D+)
/Project Architecture/Main/D-: IC406.6 (I/O1), X403.A7 (D-), X403.B7 (D-)
/Project Architecture/Main/D_{2}+: IC408.4 (I/O2), X404.A6 (D+), X404.B6 (D+)
/Project Architecture/Main/D_{2}-: IC408.6 (I/O1), X404.A7 (D-), X404.B7 (D-)
EN_{OC1}: IC407.12 (PRTPWR1/BC_EN1), IC409.1 (ENA), R412.2
GND: C401.2, C402.2, C403.2, C404.2, C405.2, C406.2, C407.2, C408.2, C409.2, C410.2, C411.2, C412.1, C413.1, C414.2, C415.2, C416.2, C417.2, C418.2, C419.2, D402.2 (A), D403.1 (K), IC401.2 (GND), IC402.2 (GND), IC403.3 (GND), IC403.13 (GND), IC403.17 (GND), IC404.2 (GND), IC405.6 (GND), IC406.2 (GND), IC407.16 (PRTPWR2/BC_EN2), IC407.24 (SCL/SMBCLK/CFG_SEL0), IC407.25 (HS_IND/CFG_SEL1), IC407.37 (GND), IC408.2 (GND), IC409.6 (GND), R406.2, R408.2, R409.2, R410.1, R415.2, R416.1, R417.2, R419.2, S401.2, SW401.2 (B), X401.3 (GND), X401.5 (GND), X402.2, X403.A1 (GND), X403.A12 (GND), X403.B1 (GND), X403.B12 (GND), X403.S1 (SHIELD), X404.A1 (GND), X404.A12 (GND), X404.B1 (GND), X404.B12 (GND), X404.S1 (SHIELD), Y401.2, Y401.4
unnamed: C406.1, D401.1 (K), IC402.5 (VBUS), IC405.11 (VCCB), J402.2, X401.1 (VTref)
unnamed: D403.2 (A), R407.1
unnamed: D404.2 (A), R421.1
unnamed: D404.1 (K), Q401.1 (G), R420.1, SW401.3 (C)
unnamed: IC402.6 (I/O1), R402.1
unnamed: IC402.4 (I/O2), R403.1
unnamed: C403.1, IC403.9 (~RESET), R404.2
unnamed: C408.1, IC404.4 (BP)
unnamed: IC402.1 (I/O1), IC405.8 (B3), SB402.1 (A)
unnamed: IC402.3 (I/O2), IC405.7 (B4), SB403.1 (A)
unnamed: IC405.12 (OE), R405.2, R406.1
unnamed: C418.1, IC407.14 (CRFILT)
unnamed: IC407.13 (OCS_{N1}), IC409.2 (FLGA)
unnamed: C417.1, IC407.34 (PLLFILT)
unnamed: IC407.35 (RBIAS), R417.1
unnamed: IC407.22 (SDA/SMBDATA/NON_REM1), R413.2
unnamed: IC407.28 (SUSP_IND/LOCAL_PWR/NON_REM0), R407.2, R408.1
unnamed: C412.2, IC407.33 (XTAL_{IN}), R411.1, Y401.1
unnamed: C413.2, IC407.32 (XTAL_{OUT}), R411.2, Y401.3
unnamed: C414.1, IC407.26 (~RESET), R414.2
unnamed: IC409.4 (ENB), R419.1
unnamed: Q401.3 (D), R418.1, X405.2
unnamed: R402.2, X401.4 (SWCLK/TCK)
unnamed: R403.2, X401.2 (SWDIO/TMS)
unnamed: R410.2, X403.A5 (CC1)
unnamed: R409.1, X403.B5 (CC2)
unnamed: R416.2, X404.A5 (CC1)
unnamed: R415.1, X404.B5 (CC2)
unnamed: R418.2, X404.A4 (VBUS), X404.A9 (VBUS), X404.B4 (VBUS), X404.B9 (VBUS), X405.1
RESETn: C401.1, D401.2 (A), D402.1 (K), IC405.9 (B2), IC405.10 (B1), R401.2, S401.1, SB401.1 (A), X401.10 (~RESET)
RESETn_{LV}: IC405.2 (A1), IC405.3 (A2), SB401.2 (B), X404.A8 (SBU1), X404.B8 (SBU2)
RxD_{LV}: IC403.2 (RXD), X402.1, X404.A11 (RX2+), X404.B11 (RX1+)
SWDCLK_{LV}: IC405.4 (A3), SB402.2 (B), X404.A2 (TX1+), X404.B2 (TX2+)
SWDIO_{LV}: IC405.5 (A4), SB403.2 (B), X404.A3 (TX1-), X404.B3 (TX2-)
TxD_{LV}: IC403.15 (TXD), X402.3, X404.A10 (RX2-), X404.B10 (RX1-)
USB-1-D+: IC403.6 (USBDP), IC407.4 (USBDP_{N2})
USB-1-D-: IC403.7 (USBDM), IC407.3 (USBDM_{N2})
USB-2-D+: IC407.2 (USBDP_{N1}), IC408.3 (I/O2)
USB-2-D-: IC407.1 (USBDM_{N1}), IC408.1 (I/O1)
USB-D+: IC406.3 (I/O2), IC407.31 (USBDP_{UP})
USB-D-: IC406.1 (I/O1), IC407.30 (USBDM_{UP})
V_{BUS}: C419.1, IC401.1 (IN), IC401.3 (EN), IC404.1 (IN), IC404.3 (EN), IC406.5 (VBUS), IC407.27 (VBUS), IC409.7 (IN), X403.A4 (VBUS), X403.A9 (VBUS), X403.B4 (VBUS), X403.B9 (VBUS)
V_{Watch}: IC408.5 (VBUS), IC409.8 (OUTA), Q401.2 (S), R420.2, R421.2

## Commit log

2025-09-07 Prepare release
    - Set variant to CHECKED
    - Remove unused files
    - Fix ERC errors
    - Fix DRC errors
    - Remove Power Sequencing page
    - Add block diagram
    [Block Diagram.kicad_sch, Main.kicad_sch, Power - Sequencing.kicad_sch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]
2025-09-07 Update outputs (release)
    [ZSWatch-Dock-(L1-L4)_NPTH_drill_table.csv, ZSWatch-Dock-(L1-L4)_drill_table.csv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]
2025-09-07 Push outputs from CI/CD (2025-09-07 19:59:27)
    [ZSWatch-Dock-(L1-L4)_NPTH_drill_table.csv, ZSWatch-Dock-(L1-L4)_drill_table.csv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]
2026-06-01 Push outputs from CI/CD (2026-06-01 11:18:39)
    [Revision History.kicad_sch]
